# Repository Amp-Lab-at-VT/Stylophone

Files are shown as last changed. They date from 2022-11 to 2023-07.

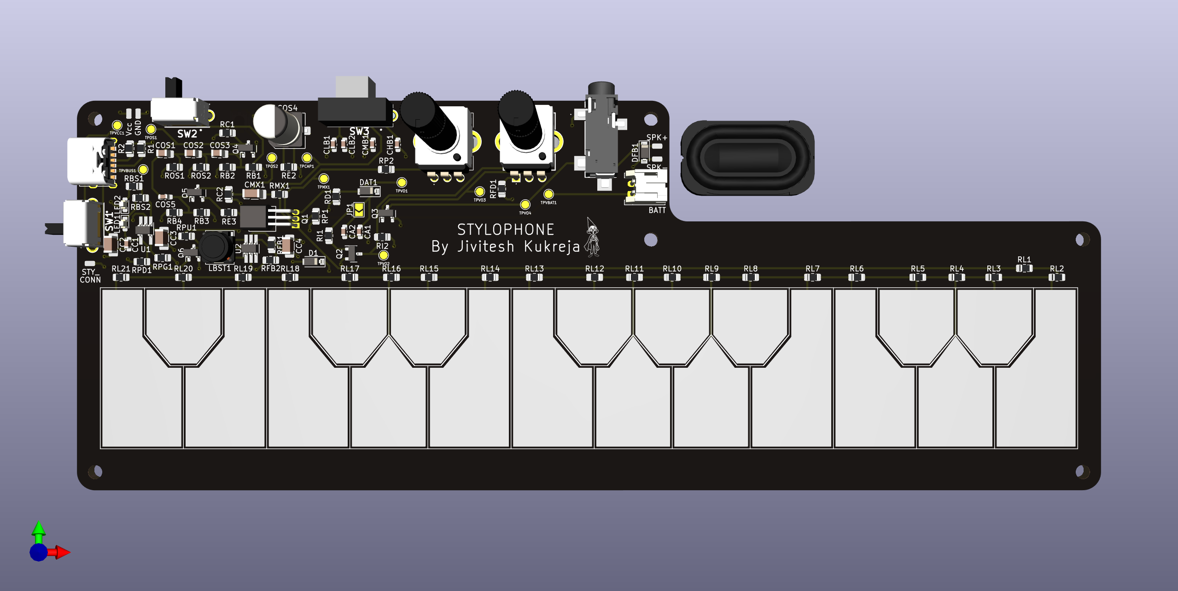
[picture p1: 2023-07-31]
Stylophone Circuit/PUT/Stylophone_with_battery_6.png

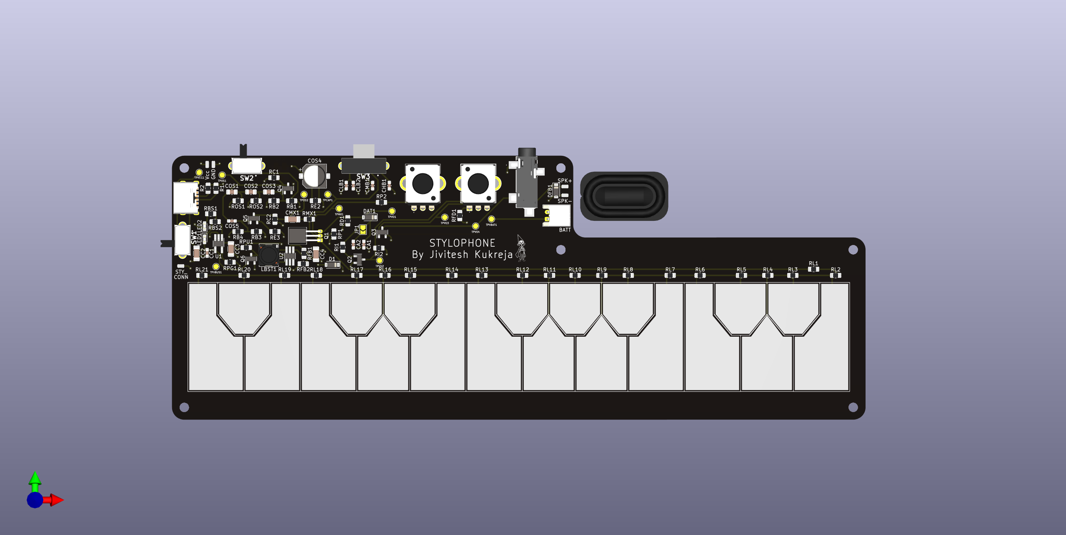
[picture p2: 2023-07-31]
Stylophone Circuit/PUT/Stylophone_with_battery_4.png

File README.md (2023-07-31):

## Members
Jivitesh Kukreja, Electrical Engineering (2024)\
jiviteshkuk26@vt.edu

## Repo Link
<a class="button is-link" href="https://github.com/Amp-Lab-at-VT/Stylophone">Stylophone</a>

## Photo
/web/img/Stylophone/hero.png

## Mentor
Richard Gibbons

## Current Status
In Progress

## Project Overview
# About Stylophone
Stylophone is a musical instrument that contains 20 keys each associated with a distinct musical note. Every time the stylus touches a key frequency associated with that key is heard on the speaker. 
Stylophone can shfit the octace associated with a key, up or down with a flick of a switch. There is also vibrato mode which is basically modulating the frequency of each key to make it sound "alienish".
# About This Project
This Project aims to reverse engineering a stylophone using a modern TLC555 timer IC and a old Programable Unijunction Transistor. 
The resevred engineered version aims to included modern features like power using type C, low power consumtion while idle and under load, support for low impedance speaker, and rechargable battery. 
This project also serves to see which sounds better the digital version based on the 555 timer or the analog version based on PUT as the orginal stylophone.

## Educational Value Added
This Project with help me learn:
1. How to design low frequency oscillators
2. How to a simple audio amplifier 
3. How to design PCB

## Tasks
1. Design a square wave generator using TLC555 that produces different frequencies with different resistor values.
2. Design an audio amplifier that drives the speaker.
3. Design a low-frequency sine wave generator for vibrato effect.
4. Power everything with a USB C connector. 

[//]: #Design Decisions

[//]: ## Design Misc

[//]: ## Steps for Documenting Your Design Process

## Fabrication Files
<a class="button is-link" href="https://github.com/Amp-Lab-at-VT/Stylophone/blob/main/Fabrication%20Files/PUT/gerber_files_with_battery.zip">Gerber Files</a>
<a class="button is-link" href="https://github.com/Amp-Lab-at-VT/Stylophone/blob/main/Fabrication%20Files/PUT/Stylophone_with_battery.csv">Bill Of Materials</a>

## Timeline
SEPTEMBER: Circuit Design\
OCTOBER: PCB Design and Protoboard Testing\
NOVEMBER: Assembly and Testing\

## Useful Links
https://www.waitingforfriday.com/?p=334 \
https://www.instructables.com/Retro-Stylophone-NE555-Based/

[//]: ## Log

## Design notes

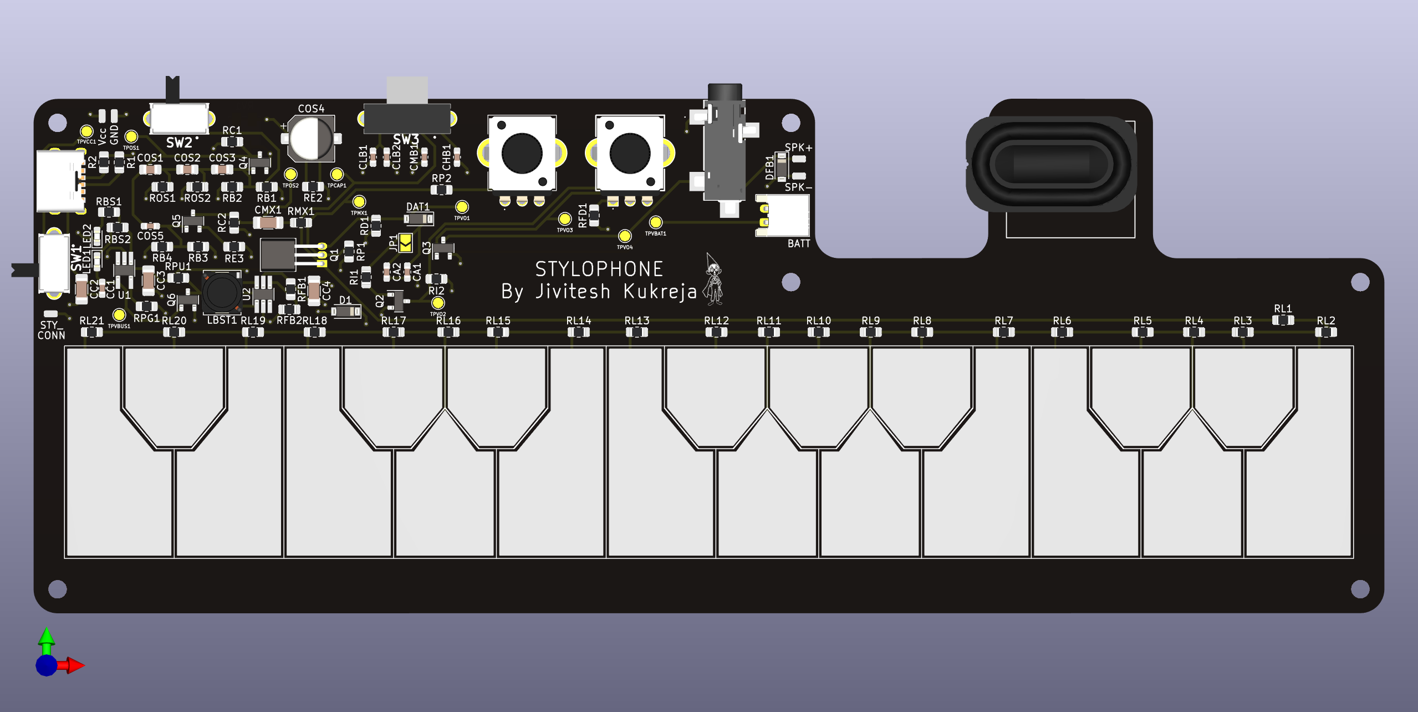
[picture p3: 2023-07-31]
Stylophone Circuit/PUT/Stylophone_with_battery_fun_design.png

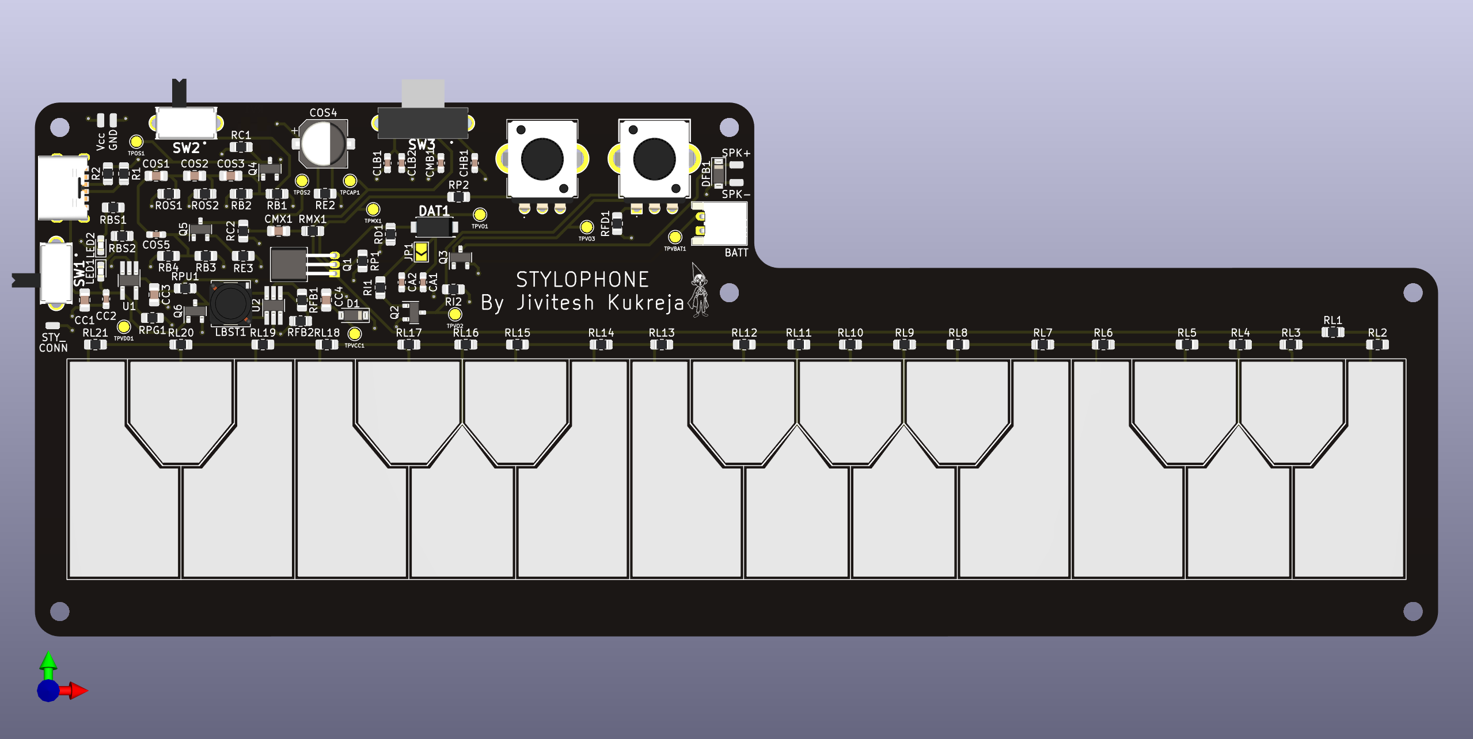
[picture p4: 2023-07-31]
Stylophone Circuit/PUT/Stylophone_with_battery.png

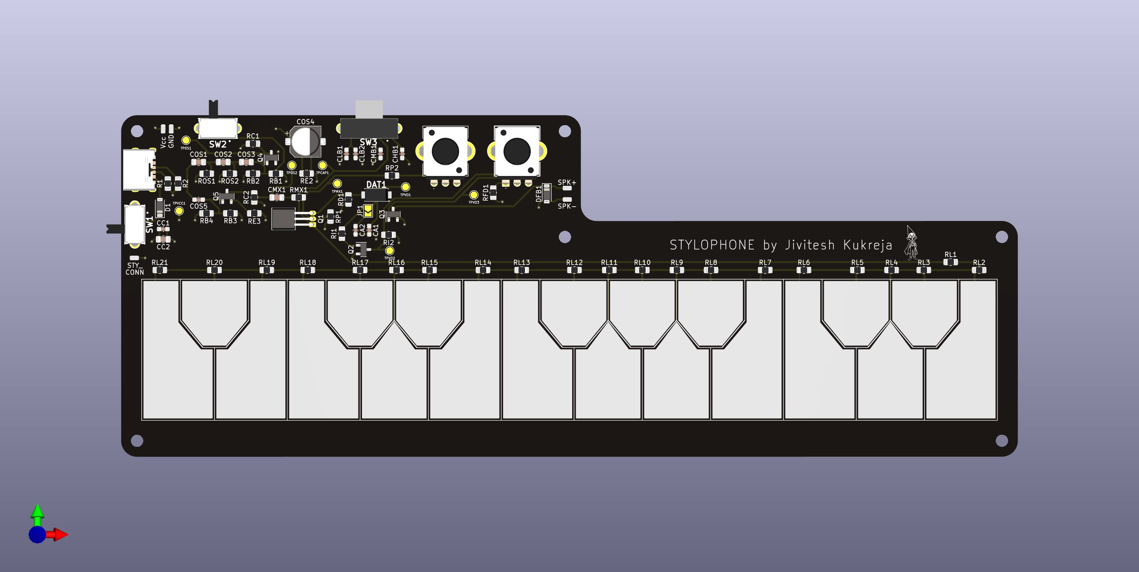
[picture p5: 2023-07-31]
Stylophone Circuit/PUT/Stylophone_without_battery.png

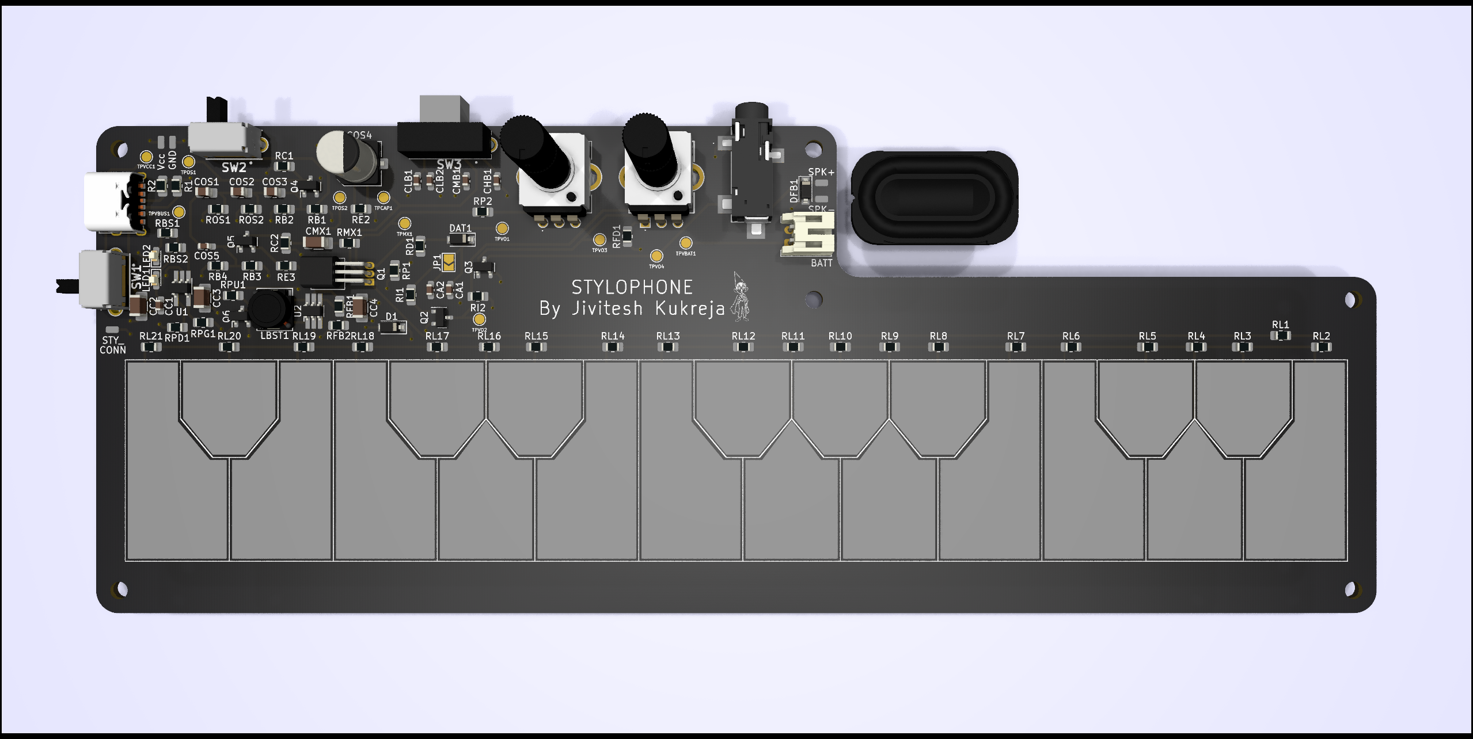
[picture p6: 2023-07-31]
Stylophone Circuit/PUT/Stylophone_with_battery_6_raytraced.png

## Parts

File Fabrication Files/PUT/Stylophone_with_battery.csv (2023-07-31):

Item | Q.R. | Reference(s) | Value | Footprint | Qty. To Order | Manufacturer | Manufacturer Part | Supplier Link | Unit Price For 1+($) | Unit Price For 10+($) | Ext. Price($) | Total Price($) | Comments
1 | 2 | CA1, CA2 | 10n | Capacitor_SMD:C_0603_1608Metric_Pad1.08x0.95mm_HandSolder | 10 | Samsung Electro-Mechanics | CL10B103KB8NNNC | https://www.mouser.com/ProductDetail/187-CL10B103KB8NNNC | 0.1 | 0.025 | 0.25 | 59.387
2 | 5 | CC1, CLB1, CLB2, CMB1, COS5 | 100n | Capacitor_SMD:C_0603_1608Metric_Pad1.08x0.95mm_HandSolder | 15 | Samsung Electro-Mechanics | CL10B104KB8NNNC | https://www.mouser.com/ProductDetail/187-CL10B104KB8NNNC | 0.1 | 0.028 | 0.42
3 | 1 | CHB1 | 47n | Capacitor_SMD:C_0603_1608Metric_Pad1.08x0.95mm_HandSolder | 10 | Samsung Electro-Mechanics | CL10B473KB8NNNC | https://www.mouser.com/ProductDetail/187-CL10B473KB8NNNC | 0.1 | 0.031 | 0.31
4 | 4 | CC2, CC3, CC4, CMX1 | 10u | Capacitor_SMD:C_1206_3216Metric_Pad1.33x1.80mm_HandSolder | 12 | Samsung Electro-Mechanics | CL31B106KBHNNNE | https://www.mouser.com/ProductDetail/187-CL31B106KBHNNNE | 0.33 | 0.232 | 2.784
5 | 3 | COS1, COS2, COS3 | 0.47u | Capacitor_SMD:C_0805_2012Metric_Pad1.18x1.45mm_HandSolder | 10 | Samsung Electro-Mechanics | CL21B474KBFNNNF | https://www.mouser.com/ProductDetail/187-CL21B474KBFNNNF | 0.1 | 0.06 | 0.6
6 | 1 | COS4 | 220u | Capacitor_SMD:CP_Elec_6.3x7.7 | 3 | Lelon | VZL221M1CTR-0607 | https://www.mouser.com/ProductDetail/140-VZL221M1CTR-0607 | 0.19 |  | 0.57 |  | UWT1V221MNL1GS, 865080453013, https://www.mouser.com/c/passive-components/capacitors/?capacitance=220%20uF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
7a | 3 | D1, DFB1, DAT1 | D_Schottky | Diode_SMD:D_SOD-123 | 10 | Nexperia | PMEG2005EGWX | https://www.mouser.com/ProductDetail/841-PMEG2005EGWX | 0.34 | 0.28 | 2.8
7b | 3 | D1, DFB2, DAT1 | D_Schottky | Diode_SMD:D_SOD-124 | 10 | Micro Commercial Components (MCC) | MBR0530-TP | https://www.mouser.com/ProductDetail/833-MBR0530-TP | 0.2 | 0.166 | 1.66
8 | 1 | J1 | USB_C_Receptacle_USB2.0 | LIB_GCT-USB4125-GF-A-190:GCTUSB4125GFA190 | 3 | Global Connector Technology (GCT) | USB4125-GF-A-0190 | https://www.mouser.com/ProductDetail/640-USB4125-GF-A-190 | 0.67 |  | 2.01
9 | 1 | J27 | Conn_01x02_Female | Connector_JST:JST_PH_S2B-PH-K_1x02_P2.00mm_Horizontal | 3 | JST Sales America Inc. | S2B-PH-K-S | https://www.digikey.com/en/products/detail/jst-sales-america-inc/S2B-PH-K-S-LF-SN/926626 | 0.17 |  | 0.51
10 | 1 | J28 | AudioJack2_Ground_SwitchT | SJ2-3593B-SMT-TR:SJ23593BSMTTR | 3 | CUI Devices | SJ2-3593B-SMT-TR | https://www.mouser.com/ProductDetail/490-SJ2-3593B-SMT-TR | 1.26 |  | 3.78
11 | 1 | LBST1 | 4.7u | 74408053004:74408053004_5030 | 3 | Wurth Elektronik | 74408053004 | https://www.mouser.com/ProductDetail/710-74408053004 | 1.04 |  | 3.12
12 | 1 | LED1 | Red | LED_SMD:LED_0603_1608Metric_Pad1.05x0.95mm_HandSolder | 3 | Wurth Elektronik | 150060SS75000 | https://www.mouser.com/ProductDetail/710-150060SS75000 | 0.15 |  | 0.45
13 | 1 | LED2 | Green | LED_SMD:LED_0603_1608Metric_Pad1.05x0.95mm_HandSolder | 3 | Wurth Elektronik | 150060VS75000 | https://www.mouser.com/ProductDetail/710-150060VS75000 | 0.15 |  | 0.45
14 | 1 | Q1 | 2N6027 | Package_TO_SOT_THT:TO-92_Inline_Horizontal2 | 3 | - | - | - | - |  | - |  | Acquired
15 | 3 | Q2, Q4, Q5 | MMBT3904L | Package_TO_SOT_SMD:SOT-23 | 9 | onsemi | MMBT3904LT3G | https://www.mouser.com/ProductDetail/863-MMBT3904LT3G | 0.13 |  | 1.17
16a | 1 | Q3 | pmos | Package_TO_SOT_SMD:SOT-23 | 3 | Microchip Technology | TP0610T-G | https://www.mouser.com/ProductDetail/689-TP0610T-G | 0.92 |  | 2.76
16b | 1 | Q3 | pmos | Package_TO_SOT_SMD:SOT-23 | 3 | Diodes Incorporated | DMP3099L-7 | https://www.mouser.com/ProductDetail/621-DMP3099L-7 | 0.34 |  | 1.02
17 | 1 | Q6 | 2N7002 | Package_TO_SOT_SMD:SOT-23 | 3 | onsemi | 2N7002LT1G | https://www.mouser.com/ProductDetail/863-2N7002LT1G | 0.29 |  | 0.87
18 | 2 | R1, R2 | 5.1k | Resistor_SMD:R_0805_2012Metric_Pad1.20x1.40mm_HandSolder | 10 | KOA Speer | RK73H2ATTD5101F | https://www.mouser.com/ProductDetail/660-RK73H2ATTD5101F | 0.1 | 0.021 | 0.21
19 | 1 | RB1 | 68k | Resistor_SMD:R_0805_2012Metric_Pad1.20x1.40mm_HandSolder | 10 | KOA Speer | RK73H2ATTD6802F | https://www.mouser.com/ProductDetail/660-RK73H2ATTD6802F | 0.1 | 0.021 | 0.21
20 | 1 | RB2 | 18k | Resistor_SMD:R_0805_2012Metric_Pad1.20x1.40mm_HandSolder | 10 | KOA Speer | RK73H2ATTD1802F | https://www.mouser.com/ProductDetail/660-RK73H2ATTD1802F | 0.1 | 0.021 | 0.21
21 | 1 | RB3 | 820k | Resistor_SMD:R_0805_2012Metric_Pad1.20x1.40mm_HandSolder | 10 | KOA Speer | RK73H2ATTD8203F | https://www.mouser.com/ProductDetail/660-RK73H2ATTD8203F | 0.1 | 0.021 | 0.21
22 | 1 | RB4 | 390k | Resistor_SMD:R_0805_2012Metric_Pad1.20x1.40mm_HandSolder | 10 | KOA Speer | RK73H2ATTD3903F | https://www.mouser.com/ProductDetail/660-RK73H2ATTD3903F | 0.1 | 0.021 | 0.21
23 | 2 | RBS1, RBS2 | 220 | Resistor_SMD:R_0805_2012Metric_Pad1.20x1.40mm_HandSolder | 10 | KOA Speer | RK73H2ATTD2200F | https://www.mouser.com/ProductDetail/660-RK73H2ATTD2200F | 0.1 | 0.021 | 0.21
24 | 2 | RC1, RL19 | 6.8k | Resistor_SMD:R_0805_2012Metric_Pad1.20x1.40mm_HandSolder | 10 | KOA Speer | RK73H2ATTD6801F | https://www.mouser.com/ProductDetail/660-RK73H2ATTD6801F | 0.1 | 0.021 | 0.21
25 | 5 | RC2, ROS1, ROS2, RPU1, RPD1 | 12k | Resistor_SMD:R_0805_2012Metric_Pad1.20x1.40mm_HandSolder | 15 | KOA Speer | RK73H2ATTD1202F | https://www.mouser.com/ProductDetail/660-RK73H2ATTD1202F | 0.1 | 0.021 | 0.252
26 | 1 | RD1 | 47 | Resistor_SMD:R_0805_2012Metric_Pad1.20x1.40mm_HandSolder | 10 | KOA Speer | RK73H2ATTD47R0F | https://www.mouser.com/ProductDetail/660-RK73H2ATTD47R0F | 0.1 | 0.021 | 0.21
27 | 7 | RE2, RI2, RL2, RL3, RMX1, RP1, RPG1 | 2.2k | Resistor_SMD:R_0805_2012Metric_Pad1.20x1.40mm_HandSolder | 21 | KOA Speer | RK73H2ATTD2201F | https://www.mouser.com/ProductDetail/660-RK73H2ATTD2201F | 0.1 | 0.021 | 0.441
28 | 5 | RE3, RL16, RL17, RL18, RL20 | 5.6k | Resistor_SMD:R_0805_2012Metric_Pad1.20x1.40mm_HandSolder | 15 | KOA Speer | RK73H2ATTD5601F | https://www.mouser.com/ProductDetail/660-RK73H2ATTD5601F | 0.1 | 0.021 | 0.315
29 | 1 | RFB1 | 900k | Resistor_SMD:R_0805_2012Metric_Pad1.20x1.40mm_HandSolder | 10 | KOA Speer | RK73H2ATTD9093F | https://www.mouser.com/ProductDetail/660-RK73H2ATTD9093F | 0.1 | 0.021 | 0.21
30 | 1 | RFB2 | 100k | Resistor_SMD:R_0805_2012Metric_Pad1.20x1.40mm_HandSolder | 10 | KOA Speer | RK73H2ATTD1003F | https://www.mouser.com/ProductDetail/660-RK73H2ATTD1003F | 0.1 | 0.021 | 0.21
31 | 3 | RFD1, RL4, RL5 | 2.7k | Resistor_SMD:R_0805_2012Metric_Pad1.20x1.40mm_HandSolder | 10 | KOA Speer | RK73H2ATTD2701F | https://www.mouser.com/ProductDetail/660-RK73H2ATTD2701F | 0.1 | 0.021 | 0.21
32 | 2 | RI1, RL1 | 39k | Resistor_SMD:R_0805_2012Metric_Pad1.20x1.40mm_HandSolder | 10 | KOA Speer | RK73H2ATTD3902F | https://www.mouser.com/ProductDetail/660-RK73H2ATTD3902F | 0.1 | 0.021 | 0.21
33 | 4 | RL6, RL7, RL8, RL9 | 3.3k | Resistor_SMD:R_0805_2012Metric_Pad1.20x1.40mm_HandSolder | 12 | KOA Speer | RK73H2ATTD3301F | https://www.mouser.com/ProductDetail/660-RK73H2ATTD3301F | 0.1 | 0.021 | 0.252
34 | 3 | RL10, RL11, RL12 | 3.9k | Resistor_SMD:R_0805_2012Metric_Pad1.20x1.40mm_HandSolder | 10 | KOA Speer | RK73H2ATTD3901F | https://www.mouser.com/ProductDetail/660-RK73H2ATTD3901F | 0.1 | 0.021 | 0.21
35 | 3 | RL13, RL14, RL15 | 4.7k | Resistor_SMD:R_0805_2012Metric_Pad1.20x1.40mm_HandSolder | 10 | KOA Speer | RK73H2ATTD4701F | https://www.mouser.com/ProductDetail/660-RK73H2ATTD4701F | 0.1 | 0.021 | 0.21
36 | 1 | RL21 | 8.2k | Resistor_SMD:R_0805_2012Metric_Pad1.20x1.40mm_HandSolder | 10 | KOA Speer | RK73H2ATTD8201F | https://www.mouser.com/ProductDetail/660-RK73H2ATTD8201F | 0.1 | 0.021 | 0.21
37 | 1 | RP2 | 1.8k | Resistor_SMD:R_0805_2012Metric_Pad1.20x1.40mm_HandSolder | 10 | KOA Speer | RK73H2ATTD1801F | https://www.mouser.com/ProductDetail/660-RK73H2ATTD1801F | 0.1 | 0.021 | 0.21
38 | 1 | RV1 | R_Potentiometer_Trim(100) | TC33X-2-101E:TC33X2503E | 3 | Bourns | TC33X-2-101E | https://www.mouser.com/ProductDetail/652-TC33X-2-101E | 0.28 |  | 0.84
39 | 2 | SW1, SW2 | SW_SPDT | OS102011MA1QN1:OS102011MA1QN1 | 6 | C&K Switches | OS102011MA1QN1 | https://www.mouser.com/ProductDetail/611-OS102011MA1QN1 | 0.5 |  | 3
40 | 1 | SW3 | SW_SP3T | OS103011MA7QP1:OS103011MA7QP1 | 3 | C&K Switches | OS103011MA7QP1 | https://www.mouser.com/ProductDetail/611-OS103011MA7QP1 | 0.58 |  | 1.74
41 | 1 | U1 | MCP73831T-4ADI_OT | Package_TO_SOT_SMD:TSOT-23-5_HandSoldering | 3 | Microchip Technology | MCP73831T-4ADI/OT | https://www.mouser.com/ProductDetail/579-MCP73831T4ADIOT | 0.76 |  | 2.28
42 | 1 | U2 | DIO6305B | Package_TO_SOT_SMD:TSOT-23-6_HandSoldering | 3 | DIOO Microcircuits | DIO6305BCST6 | https://www.mouser.com/ProductDetail/453-DIO6305BCST6 | 0.6 |  | 1.8
43 | 1 | VR1 | PTV09A-4025F-B102 | PTV09A-4025F-B102:PTV09A4025FB102 | 3 | Bourns | PTV09A-4025F-B102 | https://www.mouser.com/ProductDetail/652-PTV09A-4025FB102 | 1.01 |  | 3.03
44 | 1 | VR2 | PTV09A-4025F-A103 | PTV09A-4025F-A103:PTV09A4025FA103 | 3 | Bourns | PTV09A-4025F-A103 | https://www.mouser.com/ProductDetail/652-PTV09A4025FA103 | 1.01 |  | 3.03
45 | 1 | - | Lithium Ion Polymer Battery - 3.7v 1200mAh | - | 1 | Adafruit | 258 | https://www.adafruit.com/product/258 | 9.95 |  | 9.95
46 | 1 | - | Speaker, 25 x 14mm rectangle, 5mm deep | - | 1 | CUI Devices | CMS-25145-28SP-67 | https://www.mouser.com/ProductDetail/490-CMS-25145-28SP67 | 3.5 |  | 3.5

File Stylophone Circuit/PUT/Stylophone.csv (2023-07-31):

Source: | C:\Users\jivit\Documents\Stylophone\Amp Lab Project Repo\Stylophone\Stylophone Circuit\PUT\Stylophone.kicad_sch
Date: | 21-07-2023 8.14.33 PM
Tool: | Eeschema (6.0.7)
Generator: | C:\Program Files\KiCad\6.0\bin\scripting\plugins/bom_csv_grouped_by_value.py
Component Count: | 128
Individual Components:
Item | Qty | Reference(s) | Value | LibPart | Footprint | Datasheet | Datasheet_1 | Footprint_1 | Height | Manufacturer_Name | Manufacturer_Part_Number | Mouser Part Number | Mouser Price/Stock
 |  | CA1 | 10n | pspice:C | Capacitor_SMD:C_0603_1608Metric_Pad1.08x0.95mm_HandSolder | ~
 |  | CA2 | 10n | pspice:C | Capacitor_SMD:C_0603_1608Metric_Pad1.08x0.95mm_HandSolder | ~
 |  | CC1 | 100n | pspice:C | Capacitor_SMD:C_0603_1608Metric_Pad1.08x0.95mm_HandSolder | ~
 |  | CC2 | 10u | pspice:C | Capacitor_SMD:C_1206_3216Metric_Pad1.33x1.80mm_HandSolder | ~
 |  | CC3 | 10u | pspice:C | Capacitor_SMD:C_1206_3216Metric_Pad1.33x1.80mm_HandSolder | ~
 |  | CC4 | 10u | pspice:C | Capacitor_SMD:C_1206_3216Metric_Pad1.33x1.80mm_HandSolder | ~
 |  | CHB1 | 47n | pspice:C | Capacitor_SMD:C_0603_1608Metric_Pad1.08x0.95mm_HandSolder | ~
 |  | CLB1 | 100n | pspice:C | Capacitor_SMD:C_0603_1608Metric_Pad1.08x0.95mm_HandSolder | ~
 |  | CLB2 | 100n | pspice:C | Capacitor_SMD:C_0603_1608Metric_Pad1.08x0.95mm_HandSolder | ~
 |  | CMB1 | 100n | pspice:C | Capacitor_SMD:C_0603_1608Metric_Pad1.08x0.95mm_HandSolder | ~
 |  | CMX1 | 10u | pspice:C | Capacitor_SMD:C_1206_3216Metric_Pad1.33x1.80mm_HandSolder | ~
 |  | COS1 | 0.47u | pspice:C | Capacitor_SMD:C_0805_2012Metric_Pad1.18x1.45mm_HandSolder | ~
 |  | COS2 | 0.47u | pspice:C | Capacitor_SMD:C_0805_2012Metric_Pad1.18x1.45mm_HandSolder | ~
 |  | COS3 | 0.47u | pspice:C | Capacitor_SMD:C_0805_2012Metric_Pad1.18x1.45mm_HandSolder | ~
 |  | COS4 | 220u | pspice:C | Capacitor_SMD:CP_Elec_6.3x7.7 | ~
 |  | COS5 | 100n | pspice:C | Capacitor_SMD:C_0603_1608Metric_Pad1.08x0.95mm_HandSolder | ~
 |  | D1 | D_Schottky | Device:D_Schottky | Diode_SMD:D_SOD-123 | ~
 |  | DAT1 | D_Schottky | S1A:S1A | Diode_SMD:D_SOD-123 | https://www.mouser.com/datasheet/2/308/1/S1M_D-2320166.pdf | http://www.onsemi.com/pub/Collateral/S1M-D.pdf | DIOM5227X270N | 2.7 | onsemi | S1A | 512-S1A | https://www.mouser.co.uk/ProductDetail/onsemi-Fairchild/S1A?qs=RJwZ8kJo1mjAagviH5vK9g%3D%3D
 |  | DFB1 | D_Schottky | Device:D_Schottky | Diode_SMD:D_SOD-123 | ~
 |  | H1 | MountingHole | Mechanical:MountingHole | MountingHole:MountingHole_2.7mm_M2.5 | ~
 |  | H2 | MountingHole | Mechanical:MountingHole | MountingHole:MountingHole_2.7mm_M2.5 | ~
 |  | H3 | MountingHole | Mechanical:MountingHole | MountingHole:MountingHole_2.7mm_M2.5 | ~
 |  | H4 | MountingHole | Mechanical:MountingHole | MountingHole:MountingHole_2.7mm_M2.5 | ~
 |  | H5 | MountingHole | Mechanical:MountingHole | MountingHole:MountingHole_2.7mm_M2.5 | ~
 |  | H6 | MountingHole | Mechanical:MountingHole | MountingHole:MountingHole_2.7mm_M2.5 | ~
 |  | J1 | USB_C_Receptacle_USB2.0 | Connector:USB_C_Receptacle_USB2.0 | LIB_GCT-USB4125-GF-A-190:GCTUSB4125GFA190 | https://www.usb.org/sites/default/files/documents/usb_type-c.zip
 |  | J2 | Conn_01x01_Female | Connector:Conn_01x01_Female | Connector_Wire:SolderWirePad_1x01_SMD_1x2mm | ~
 |  | J3 | Conn_01x01_Female | Connector:Conn_01x01_Female | Connector_Wire:SolderWirePad_1x01_SMD_1x2mm | ~
 |  | J4 | Conn_01x01_Female | Connector:Conn_01x01_Female | Connector_Wire:SolderWirePad_1x01_SMD_1x2mm | ~
 |  | J5 | Conn_01x01_Female | Connector:Conn_01x01_Female | Stylophone_Lib:Note-Left | ~
 |  | J6 | Conn_01x01_Female | Connector:Conn_01x01_Female | Stylophone_Lib:Note-Sharp | ~
 |  | J7 | Conn_01x01_Female | Connector:Conn_01x01_Female | Stylophone_Lib:Note-Right | ~
 |  | J8 | Conn_01x01_Female | Connector:Conn_01x01_Female | Stylophone_Lib:Note-Left | ~
 |  | J9 | Conn_01x01_Female | Connector:Conn_01x01_Female | Stylophone_Lib:Note-Sharp | ~
 |  | J10 | Conn_01x01_Female | Connector:Conn_01x01_Female | Stylophone_Lib:Note-Center | ~
 |  | J11 | Conn_01x01_Female | Connector:Conn_01x01_Female | Stylophone_Lib:Note-Sharp | ~
 |  | J12 | Conn_01x01_Female | Connector:Conn_01x01_Female | Stylophone_Lib:Note-Right | ~
 |  | J13 | Conn_01x01_Female | Connector:Conn_01x01_Female | Stylophone_Lib:Note-Left | ~
 |  | J14 | Conn_01x01_Female | Connector:Conn_01x01_Female | Stylophone_Lib:Note-Sharp | ~
 |  | J15 | Conn_01x01_Female | Connector:Conn_01x01_Female | Stylophone_Lib:Note-Right | ~
 |  | J16 | Conn_01x01_Female | Connector:Conn_01x01_Female | Stylophone_Lib:Note-Sharp | ~
 |  | J17 | Conn_01x01_Female | Connector:Conn_01x01_Female | Stylophone_Lib:Note-Center | ~
 |  | J18 | Conn_01x01_Female | Connector:Conn_01x01_Female | Stylophone_Lib:Note-Sharp | ~
 |  | J19 | Conn_01x01_Female | Connector:Conn_01x01_Female | Stylophone_Lib:Note-Left | ~
 |  | J20 | Conn_01x01_Female | Connector:Conn_01x01_Female | Stylophone_Lib:Note-Right | ~
 |  | J21 | Conn_01x01_Female | Connector:Conn_01x01_Female | Stylophone_Lib:Note-Sharp | ~
 |  | J22 | Conn_01x01_Female | Connector:Conn_01x01_Female | Stylophone_Lib:Note-Center | ~
 |  | J23 | Conn_01x01_Female | Connector:Conn_01x01_Female | Stylophone_Lib:Note-Sharp | ~
 |  | J24 | Conn_01x01_Female | Connector:Conn_01x01_Female | Stylophone_Lib:Note-Center | ~
 |  | J25 | Conn_01x01_Female | Connector:Conn_01x01_Female | Connector_Wire:SolderWirePad_1x01_SMD_1x2mm | ~
 |  | J26 | Conn_01x01_Female | Connector:Conn_01x01_Female | Connector_Wire:SolderWirePad_1x01_SMD_1x2mm | ~
 |  | J27 | Conn_01x02_Female | Connector:Conn_01x02_Female | Connector_JST:JST_PH_S2B-PH-K_1x02_P2.00mm_Horizontal | ~
 |  | J28 | AudioJack2_Ground_SwitchT | Connector:AudioJack2_Ground_SwitchT | SJ2-3593B-SMT-TR:SJ23593BSMTTR | ~
 |  | JP1 | SolderJumper_2_Open | Jumper:SolderJumper_2_Open | Jumper:SolderJumper-2_P1.3mm_Open_TrianglePad1.0x1.5mm | ~
 |  | LBST1 | 4.7u | pspice:INDUCTOR | 74408053004:74408053004_5030 | ~
 |  | LED1 | Red | Device:LED | LED_SMD:LED_0603_1608Metric_Pad1.05x0.95mm_HandSolder | ~
 |  | LED2 | Green | Device:LED | LED_SMD:LED_0603_1608Metric_Pad1.05x0.95mm_HandSolder | ~
 |  | Q1 | 2N6027 | Transistor_PUT:2N6027 | Package_TO_SOT_THT:TO-92_Inline_Horizontal2 | https://www.mouser.com/datasheet/2/68/get_document-1518606.pdf
 |  | Q2 | MMBT3904L | Transistor_BJT:MMBT3904 | Package_TO_SOT_SMD:SOT-23 | https://www.onsemi.com/pub/Collateral/2N3903-D.PDF
 |  | Q3 | TP0610T | Transistor_FET:TP0610T | Package_TO_SOT_SMD:SOT-23 | http://www.vishay.com/docs/70209/70209.pdf
 |  | Q4 | MMBT3904L | Transistor_BJT:MMBT3904 | Package_TO_SOT_SMD:SOT-23 | https://www.onsemi.com/pub/Collateral/2N3903-D.PDF
 |  | Q5 | MMBT3904L | Transistor_BJT:MMBT3904 | Package_TO_SOT_SMD:SOT-23 | https://www.onsemi.com/pub/Collateral/2N3903-D.PDF
 |  | Q6 | 2N7002 | Transistor_FET:2N7002 | Package_TO_SOT_SMD:SOT-23 | https://www.onsemi.com/pub/Collateral/NDS7002A-D.PDF
 |  | R1 | 5.1k | Device:R | Resistor_SMD:R_0805_2012Metric_Pad1.20x1.40mm_HandSolder | ~
 |  | R2 | 5.1k | Device:R | Resistor_SMD:R_0805_2012Metric_Pad1.20x1.40mm_HandSolder | ~
 |  | RB1 | 68k | Device:R | Resistor_SMD:R_0805_2012Metric_Pad1.20x1.40mm_HandSolder | ~
 |  | RB2 | 18k | Device:R | Resistor_SMD:R_0805_2012Metric_Pad1.20x1.40mm_HandSolder | ~
 |  | RB3 | 820k | Device:R | Resistor_SMD:R_0805_2012Metric_Pad1.20x1.40mm_HandSolder | ~
 |  | RB4 | 390k | Device:R | Resistor_SMD:R_0805_2012Metric_Pad1.20x1.40mm_HandSolder | ~
 |  | RBS1 | 220 | Device:R | Resistor_SMD:R_0805_2012Metric_Pad1.20x1.40mm_HandSolder | ~
 |  | RBS2 | 220 | Device:R | Resistor_SMD:R_0805_2012Metric_Pad1.20x1.40mm_HandSolder | ~
 |  | RC1 | 6.8k | Device:R | Resistor_SMD:R_0805_2012Metric_Pad1.20x1.40mm_HandSolder | ~
 |  | RC2 | 12k | Device:R | Resistor_SMD:R_0805_2012Metric_Pad1.20x1.40mm_HandSolder | ~
 |  | RD1 | 47 | Device:R | Resistor_SMD:R_0805_2012Metric_Pad1.20x1.40mm_HandSolder | ~
 |  | RE2 | 2.2k | Device:R | Resistor_SMD:R_0805_2012Metric_Pad1.20x1.40mm_HandSolder | ~
 |  | RE3 | 5.6k | Device:R | Resistor_SMD:R_0805_2012Metric_Pad1.20x1.40mm_HandSolder | ~
 |  | RFB1 | 900k | Device:R | Resistor_SMD:R_0805_2012Metric_Pad1.20x1.40mm_HandSolder | ~
 |  | RFB2 | 100k | Device:R | Resistor_SMD:R_0805_2012Metric_Pad1.20x1.40mm_HandSolder | ~
 |  | RFD1 | 2.7k | Device:R | Resistor_SMD:R_0805_2012Metric_Pad1.20x1.40mm_HandSolder | ~
 |  | RI1 | 39k | Device:R | Resistor_SMD:R_0805_2012Metric_Pad1.20x1.40mm_HandSolder | ~
 |  | RI2 | 2.2k | Device:R | Resistor_SMD:R_0805_2012Metric_Pad1.20x1.40mm_HandSolder | ~
 |  | RL1 | 39k | Device:R | Resistor_SMD:R_0805_2012Metric_Pad1.20x1.40mm_HandSolder | ~
 |  | RL2 | 2.2k | Device:R | Resistor_SMD:R_0805_2012Metric_Pad1.20x1.40mm_HandSolder | ~
 |  | RL3 | 2.2k | Device:R | Resistor_SMD:R_0805_2012Metric_Pad1.20x1.40mm_HandSolder | ~
 |  | RL4 | 2.7k | Device:R | Resistor_SMD:R_0805_2012Metric_Pad1.20x1.40mm_HandSolder | ~
 |  | RL5 | 2.7k | Device:R | Resistor_SMD:R_0805_2012Metric_Pad1.20x1.40mm_HandSolder | ~
 |  | RL6 | 3.3k | Device:R | Resistor_SMD:R_0805_2012Metric_Pad1.20x1.40mm_HandSolder | ~
 |  | RL7 | 3.3k | Device:R | Resistor_SMD:R_0805_2012Metric_Pad1.20x1.40mm_HandSolder | ~
 |  | RL8 | 3.3k | Device:R | Resistor_SMD:R_0805_2012Metric_Pad1.20x1.40mm_HandSolder | ~
 |  | RL9 | 3.3k | Device:R | Resistor_SMD:R_0805_2012Metric_Pad1.20x1.40mm_HandSolder | ~
 |  | RL10 | 3.9k | Device:R | Resistor_SMD:R_0805_2012Metric_Pad1.20x1.40mm_HandSolder | ~
 |  | RL11 | 3.9k | Device:R | Resistor_SMD:R_0805_2012Metric_Pad1.20x1.40mm_HandSolder | ~
 |  | RL12 | 3.9k | Device:R | Resistor_SMD:R_0805_2012Metric_Pad1.20x1.40mm_HandSolder | ~
 |  | RL13 | 4.7k | Device:R | Resistor_SMD:R_0805_2012Metric_Pad1.20x1.40mm_HandSolder | ~
 |  | RL14 | 4.7k | Device:R | Resistor_SMD:R_0805_2012Metric_Pad1.20x1.40mm_HandSolder | ~
 |  | RL15 | 4.7k | Device:R | Resistor_SMD:R_0805_2012Metric_Pad1.20x1.40mm_HandSolder | ~
 |  | RL16 | 5.6k | Device:R | Resistor_SMD:R_0805_2012Metric_Pad1.20x1.40mm_HandSolder | ~
 |  | RL17 | 5.6k | Device:R | Resistor_SMD:R_0805_2012Metric_Pad1.20x1.40mm_HandSolder | ~
 |  | RL18 | 5.6k | Device:R | Resistor_SMD:R_0805_2012Metric_Pad1.20x1.40mm_HandSolder | ~
 |  | RL19 | 6.8k | Device:R | Resistor_SMD:R_0805_2012Metric_Pad1.20x1.40mm_HandSolder | ~
 |  | RL20 | 5.6k | Device:R | Resistor_SMD:R_0805_2012Metric_Pad1.20x1.40mm_HandSolder | ~
 |  | RL21 | 8.2k | Device:R | Resistor_SMD:R_0805_2012Metric_Pad1.20x1.40mm_HandSolder | ~
 |  | RMX1 | 2.2k | Device:R | Resistor_SMD:R_0805_2012Metric_Pad1.20x1.40mm_HandSolder | ~
 |  | ROS1 | 12k | Device:R | Resistor_SMD:R_0805_2012Metric_Pad1.20x1.40mm_HandSolder | ~
 |  | ROS2 | 12k | Device:R | Resistor_SMD:R_0805_2012Metric_Pad1.20x1.40mm_HandSolder | ~
 |  | RP1 | 2.2k | Device:R | Resistor_SMD:R_0805_2012Metric_Pad1.20x1.40mm_HandSolder | ~
 |  | RP2 | 1.8k | Device:R | Resistor_SMD:R_0805_2012Metric_Pad1.20x1.40mm_HandSolder | ~
 |  | RPG1 | 2.2k | Device:R | Resistor_SMD:R_0805_2012Metric_Pad1.20x1.40mm_HandSolder | ~
 |  | RPU1 | 12k | Device:R | Resistor_SMD:R_0805_2012Metric_Pad1.20x1.40mm_HandSolder | ~
 |  | RV1 | R_Potentiometer_Trim(100) | Device:R_Potentiometer_Trim | Potentiometer_SMD:Potentiometer_Bourns_3314J_Vertical | ~
 |  | SW1 | SW_SPDT | Switch:SW_SPDT | OS102011MA1QN1:OS102011MA1QN1 | ~
 |  | SW2 | SW_SPDT | Switch:SW_SPDT | OS102011MA1QN1:OS102011MA1QN1 | ~
 |  | SW3 | SW_SP3T | Switch:SW_SP3T | OS103011MA7QP1:OS103011MA7QP1 | ~
 |  | TPCAP1 | TestPoint | Connector:TestPoint | TestPoint:TestPoint_Pad_D1.5mm | ~
 |  | TPMX1 | TestPoint | Connector:TestPoint | TestPoint:TestPoint_Pad_D1.5mm | ~
 |  | TPOS1 | TestPoint | Connector:TestPoint | TestPoint:TestPoint_Pad_D1.5mm | ~
 |  | TPOS2 | TestPoint | Connector:TestPoint | TestPoint:TestPoint_Pad_D1.5mm | ~
 |  | TPVBAT1 | TestPoint | Connector:TestPoint | TestPoint:TestPoint_Pad_D1.5mm | ~
 |  | TPVBUS1 | TestPoint | Connector:TestPoint | TestPoint:TestPoint_Pad_D1.5mm | ~
 |  | TPVCC1 | TestPoint | Connector:TestPoint | TestPoint:TestPoint_Pad_D1.5mm | ~
 |  | TPVO1 | TestPoint | Connector:TestPoint | TestPoint:TestPoint_Pad_D1.5mm | ~
 |  | TPVO2 | TestPoint | Connector:TestPoint | TestPoint:TestPoint_Pad_D1.5mm | ~
 |  | TPVO3 | TestPoint | Connector:TestPoint | TestPoint:TestPoint_Pad_D1.5mm | ~
 |  | TPVO4 | TestPoint | Connector:TestPoint | TestPoint:TestPoint_Pad_D1.5mm | ~
 |  | U1 | MCP73831T-4ADI_OT | MCP73831T-4ADI_OT:MCP73831T-4ADI_OT | Package_TO_SOT_SMD:TSOT-23-5_HandSoldering |  | https://componentsearchengine.com/Datasheets/1/MCP73831T-4ADI_OT.pdf | SOT95P270X145-5N | 1.45 | Microchip | MCP73831T-4ADI/OT | 579-MCP73831T4ADIOT | https://www.mouser.co.uk/ProductDetail/Microchip-Technology/MCP73831T-4ADI-OT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
 |  | U2 | DIO6305B | LIB_DIO6305B_sym:DIO6305B | Package_TO_SOT_SMD:TSOT-23-6_HandSoldering
 |  | VR1 | PTV09A-4025F-B102 | PTV09A-4025F-B102:PTV09A-4025F-B102 | PTV09A-4025F-B102:PTV09A4025FB102 | https://www.mouser.com/datasheet/2/54/ptv09-777818.pdf | https://datasheet.datasheetarchive.com/originals/dk/DKDS-12/224967.pdf | PTV09A4025FB102 | 25.5 | Bourns | PTV09A-4025F-B102 | 652-PTV09A-4025FB102 | https://www.mouser.co.uk/ProductDetail/Bourns/PTV09A-4025F-B102?qs=Qzws7J6gxqxMpvIOw8B%2F7Q%3D%3D
 |  | VR2 | PTV09A-4025F-A103 | PTV09A-4025F-A103:PTV09A-4025F-A103 | PTV09A-4025F-A103:PTV09A4025FA103 | https://www.mouser.com/datasheet/2/54/ptv09-777818.pdf | https://www.bourns.com/docs/Product-Datasheets/PTV09.pdf | PTV09A4025FA103 | 25.5 | Bourns | PTV09A-4025F-A103 | 652-PTV09A4025FA103 | https://www.mouser.co.uk/ProductDetail/Bourns/PTV09A-4025F-A103?qs=%2FxQVPCMPNzjerVjIRRaAEA%3D%3D
Collated Components:
Item | Qty | Reference(s) | Value | LibPart | Footprint | Datasheet | Datasheet_1 | Footprint_1 | Height | Manufacturer_Name | Manufacturer_Part_Number | Mouser Part Number | Mouser Price/Stock
1 | 2 | CA1, CA2 | 10n | pspice:C | Capacitor_SMD:C_0603_1608Metric_Pad1.08x0.95mm_HandSolder | ~
2 | 5 | CC1, CLB1, CLB2, CMB1, COS5 | 100n | pspice:C | Capacitor_SMD:C_0603_1608Metric_Pad1.08x0.95mm_HandSolder | ~
3 | 4 | CC2, CC3, CC4, CMX1 | 10u | pspice:C | Capacitor_SMD:C_1206_3216Metric_Pad1.33x1.80mm_HandSolder | ~
4 | 1 | CHB1 | 47n | pspice:C | Capacitor_SMD:C_0603_1608Metric_Pad1.08x0.95mm_HandSolder | ~
5 | 3 | COS1, COS2, COS3 | 0.47u | pspice:C | Capacitor_SMD:C_0805_2012Metric_Pad1.18x1.45mm_HandSolder | ~
6 | 1 | COS4 | 220u | pspice:C | Capacitor_SMD:CP_Elec_6.3x7.7 | ~
7 | 2 | D1, DFB1 | D_Schottky | Device:D_Schottky | Diode_SMD:D_SOD-123 | ~
8 | 1 | DAT1 | D_Schottky | S1A:S1A | Diode_SMD:D_SOD-123 | https://www.mouser.com/datasheet/2/308/1/S1M_D-2320166.pdf | http://www.onsemi.com/pub/Collateral/S1M-D.pdf | DIOM5227X270N | 2.7 | onsemi | S1A | 512-S1A | https://www.mouser.co.uk/ProductDetail/onsemi-Fairchild/S1A?qs=RJwZ8kJo1mjAagviH5vK9g%3D%3D
9 | 6 | H1, H2, H3, H4, H5, H6 | MountingHole | Mechanical:MountingHole | MountingHole:MountingHole_2.7mm_M2.5 | ~
10 | 1 | J1 | USB_C_Receptacle_USB2.0 | Connector:USB_C_Receptacle_USB2.0 | LIB_GCT-USB4125-GF-A-190:GCTUSB4125GFA190 | https://www.usb.org/sites/default/files/documents/usb_type-c.zip
11 | 5 | J2, J3, J4, J25, J26 | Conn_01x01_Female | Connector:Conn_01x01_Female | Connector_Wire:SolderWirePad_1x01_SMD_1x2mm | ~
12 | 4 | J5, J8, J13, J19 | Conn_01x01_Female | Connector:Conn_01x01_Female | Stylophone_Lib:Note-Left | ~
13 | 8 | J6, J9, J11, J14, J16, J18, J21, J23 | Conn_01x01_Female | Connector:Conn_01x01_Female | Stylophone_Lib:Note-Sharp | ~
14 | 4 | J7, J12, J15, J20 | Conn_01x01_Female | Connector:Conn_01x01_Female | Stylophone_Lib:Note-Right | ~
15 | 4 | J10, J17, J22, J24 | Conn_01x01_Female | Connector:Conn_01x01_Female | Stylophone_Lib:Note-Center | ~
16 | 1 | J27 | Conn_01x02_Female | Connector:Conn_01x02_Female | Connector_JST:JST_PH_S2B-PH-K_1x02_P2.00mm_Horizontal | ~
17 | 1 | J28 | AudioJack2_Ground_SwitchT | Connector:AudioJack2_Ground_SwitchT | SJ2-3593B-SMT-TR:SJ23593BSMTTR | ~
18 | 1 | JP1 | SolderJumper_2_Open | Jumper:SolderJumper_2_Open | Jumper:SolderJumper-2_P1.3mm_Open_TrianglePad1.0x1.5mm | ~
19 | 1 | LBST1 | 4.7u | pspice:INDUCTOR | 74408053004:74408053004_5030 | ~
20 | 1 | LED1 | Red | Device:LED | LED_SMD:LED_0603_1608Metric_Pad1.05x0.95mm_HandSolder | ~
21 | 1 | LED2 | Green | Device:LED | LED_SMD:LED_0603_1608Metric_Pad1.05x0.95mm_HandSolder | ~
22 | 1 | Q1 | 2N6027 | Transistor_PUT:2N6027 | Package_TO_SOT_THT:TO-92_Inline_Horizontal2 | https://www.mouser.com/datasheet/2/68/get_document-1518606.pdf
23 | 3 | Q2, Q4, Q5 | MMBT3904L | Transistor_BJT:MMBT3904 | Package_TO_SOT_SMD:SOT-23 | https://www.onsemi.com/pub/Collateral/2N3903-D.PDF
24 | 1 | Q3 | TP0610T | Transistor_FET:TP0610T | Package_TO_SOT_SMD:SOT-23 | http://www.vishay.com/docs/70209/70209.pdf
25 | 1 | Q6 | 2N7002 | Transistor_FET:2N7002 | Package_TO_SOT_SMD:SOT-23 | https://www.onsemi.com/pub/Collateral/NDS7002A-D.PDF
26 | 2 | R1, R2 | 5.1k | Device:R | Resistor_SMD:R_0805_2012Metric_Pad1.20x1.40mm_HandSolder | ~
27 | 1 | RB1 | 68k | Device:R | Resistor_SMD:R_0805_2012Metric_Pad1.20x1.40mm_HandSolder | ~
28 | 1 | RB2 | 18k | Device:R | Resistor_SMD:R_0805_2012Metric_Pad1.20x1.40mm_HandSolder | ~
29 | 1 | RB3 | 820k | Device:R | Resistor_SMD:R_0805_2012Metric_Pad1.20x1.40mm_HandSolder | ~
30 | 1 | RB4 | 390k | Device:R | Resistor_SMD:R_0805_2012Metric_Pad1.20x1.40mm_HandSolder | ~
31 | 2 | RBS1, RBS2 | 220 | Device:R | Resistor_SMD:R_0805_2012Metric_Pad1.20x1.40mm_HandSolder | ~
32 | 2 | RC1, RL19 | 6.8k | Device:R | Resistor_SMD:R_0805_2012Metric_Pad1.20x1.40mm_HandSolder | ~
33 | 4 | RC2, ROS1, ROS2, RPU1 | 12k | Device:R | Resistor_SMD:R_0805_2012Metric_Pad1.20x1.40mm_HandSolder | ~
34 | 1 | RD1 | 47 | Device:R | Resistor_SMD:R_0805_2012Metric_Pad1.20x1.40mm_HandSolder | ~
35 | 7 | RE2, RI2, RL2, RL3, RMX1, RP1, RPG1 | 2.2k | Device:R | Resistor_SMD:R_0805_2012Metric_Pad1.20x1.40mm_HandSolder | ~
36 | 5 | RE3, RL16, RL17, RL18, RL20 | 5.6k | Device:R | Resistor_SMD:R_0805_2012Metric_Pad1.20x1.40mm_HandSolder | ~
37 | 1 | RFB1 | 900k | Device:R | Resistor_SMD:R_0805_2012Metric_Pad1.20x1.40mm_HandSolder | ~
38 | 1 | RFB2 | 100k | Device:R | Resistor_SMD:R_0805_2012Metric_Pad1.20x1.40mm_HandSolder | ~
39 | 3 | RFD1, RL4, RL5 | 2.7k | Device:R | Resistor_SMD:R_0805_2012Metric_Pad1.20x1.40mm_HandSolder | ~
40 | 2 | RI1, RL1 | 39k | Device:R | Resistor_SMD:R_0805_2012Metric_Pad1.20x1.40mm_HandSolder | ~
41 | 4 | RL6, RL7, RL8, RL9 | 3.3k | Device:R | Resistor_SMD:R_0805_2012Metric_Pad1.20x1.40mm_HandSolder | ~
42 | 3 | RL10, RL11, RL12 | 3.9k | Device:R | Resistor_SMD:R_0805_2012Metric_Pad1.20x1.40mm_HandSolder | ~
43 | 3 | RL13, RL14, RL15 | 4.7k | Device:R | Resistor_SMD:R_0805_2012Metric_Pad1.20x1.40mm_HandSolder | ~
44 | 1 | RL21 | 8.2k | Device:R | Resistor_SMD:R_0805_2012Metric_Pad1.20x1.40mm_HandSolder | ~
45 | 1 | RP2 | 1.8k | Device:R | Resistor_SMD:R_0805_2012Metric_Pad1.20x1.40mm_HandSolder | ~
46 | 1 | RV1 | R_Potentiometer_Trim(100) | Device:R_Potentiometer_Trim | Potentiometer_SMD:Potentiometer_Bourns_3314J_Vertical | ~
47 | 2 | SW1, SW2 | SW_SPDT | Switch:SW_SPDT | OS102011MA1QN1:OS102011MA1QN1 | ~
48 | 1 | SW3 | SW_SP3T | Switch:SW_SP3T | OS103011MA7QP1:OS103011MA7QP1 | ~
49 | 11 | TPCAP1, TPMX1, TPOS1, TPOS2, TPVBAT1, TPVBUS1, TPVCC1, TPVO1, TPVO2, TPVO3, TPVO4 | TestPoint | Connector:TestPoint | TestPoint:TestPoint_Pad_D1.5mm | ~
50 | 1 | U1 | MCP73831T-4ADI_OT | MCP73831T-4ADI_OT:MCP73831T-4ADI_OT | Package_TO_SOT_SMD:TSOT-23-5_HandSoldering |  | https://componentsearchengine.com/Datasheets/1/MCP73831T-4ADI_OT.pdf | SOT95P270X145-5N | 1.45 | Microchip | MCP73831T-4ADI/OT | 579-MCP73831T4ADIOT | https://www.mouser.co.uk/ProductDetail/Microchip-Technology/MCP73831T-4ADI-OT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
51 | 1 | U2 | DIO6305B | LIB_DIO6305B_sym:DIO6305B | Package_TO_SOT_SMD:TSOT-23-6_HandSoldering
52 | 1 | VR1 | PTV09A-4025F-B102 | PTV09A-4025F-B102:PTV09A-4025F-B102 | PTV09A-4025F-B102:PTV09A4025FB102 | https://www.mouser.com/datasheet/2/54/ptv09-777818.pdf | https://datasheet.datasheetarchive.com/originals/dk/DKDS-12/224967.pdf | PTV09A4025FB102 | 25.5 | Bourns | PTV09A-4025F-B102 | 652-PTV09A-4025FB102 | https://www.mouser.co.uk/ProductDetail/Bourns/PTV09A-4025F-B102?qs=Qzws7J6gxqxMpvIOw8B%2F7Q%3D%3D
53 | 1 | VR2 | PTV09A-4025F-A103 | PTV09A-4025F-A103:PTV09A-4025F-A103 | PTV09A-4025F-A103:PTV09A4025FA103 | https://www.mouser.com/datasheet/2/54/ptv09-777818.pdf | https://www.bourns.com/docs/Product-Datasheets/PTV09.pdf | PTV09A4025FA103 | 25.5 | Bourns | PTV09A-4025F-A103 | 652-PTV09A4025FA103 | https://www.mouser.co.uk/ProductDetail/Bourns/PTV09A-4025F-A103?qs=%2FxQVPCMPNzjerVjIRRaAEA%3D%3D

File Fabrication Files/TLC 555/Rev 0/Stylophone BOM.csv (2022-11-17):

Id | Designation | Designator | Package | Quantity | Manufacturer | Manufacturer Part | Supplier Link
1 | USB_C_Receptacle_USB2.0 | J3 | GCTUSB4125GFA190 | 1 | Global Connector Technology (GCT) | USB4125-GF-A-0190 | https://www.mouser.com/ProductDetail/640-USB4125-GF-A-190
2 | TLC555xD | U1 | SOIC-8_3.9x4.9mm_P1.27mm | 1 | Texas Instruments | TLC555CD | https://www.mouser.com/ProductDetail/595-TLC555CD
3 | D_Schottky | D3,D1,D2 | D_SOD-123 | 3 | STMicroelectronics | STPS0530Z | https://www.mouser.com/ProductDetail/511-STPS0530Z
4 | 3.9k | R22,R30,R29,R31 | R_0402_1005Metric | 4 | YAGEO | RT0402FRE073K9L | https://www.mouser.com/ProductDetail/603-RT0402FRE073K9L
5 | PDB12-H4301-103BF | VR1 | PDB12H4301103BF | 1 | Bourns | PDB12-H4301-103BF | https://www.mouser.com/ProductDetail/652-PDB12-H4301103BF
6 | 5.6k | R23,R13,R12,R10 | R_0402_1005Metric | 4 | YAGEO | RT0402FRE075K6L | https://www.mouser.com/ProductDetail/603-RT0402FRE075K6L
7 | 39k | R21 | R_0402_1005Metric | 1 | YAGEO | RT0402FRE0739KL | https://www.mouser.com/ProductDetail/603-RT0402FRE0739KL
8 | 6.8k | R9,R8,R11,R7 | R_0402_1005Metric | 4 | YAGEO | RT0402FRE076K8L | https://www.mouser.com/ProductDetail/603-RT0402FRE076K8L
9 | MMBT3904L | Q2 | SOT-23 | 1 | onsemi | SMMBT3904LT1G | https://www.mouser.com/ProductDetail/863-SMMBT3904LT1G
10 | 4.7k | R15,R14 | R_0402_1005Metric | 2 | YAGEO | RT0402FRE074K7L | https://www.mouser.com/ProductDetail/603-RT0402FRE074K7L
11 | 2.7k | R25 | R_0402_1005Metric | 1 | YAGEO | RT0402DRE072K71L | https://www.mouser.com/ProductDetail/603-RT0402DRE072K71L
12 | 100k | R20 | R_0402_1005Metric | 1 | YAGEO | RT0402FRE07100KL | https://www.mouser.com/ProductDetail/603-RT0402FRE07100KL
13 | 3.3k | R24,R3,R26,R28,R27 | R_0402_1005Metric | 5 | YAGEO | RT0402FRE073K3L | https://www.mouser.com/ProductDetail/603-RT0402FRE073K3L
14 | 33k | R17,R18,R19 | R_0402_1005Metric | 3 | YAGEO | RT0402FRE0733KL | https://www.mouser.com/ProductDetail/603-RT0402FRE0733KL
15 | 5.1k | R1,R2 | R_0201_0603Metric | 2 | Vishay | TNPW02015K10BEED | https://www.mouser.com/ProductDetail/71-TNPW02015K10BEED
16 | 10n | C3 | C_0201_0603Metric | 1 | Samsung Electro-Mechanics | CL03A103KP3NNNC | https://www.mouser.com/ProductDetail/187-CL03A103KP3NNNC
17 | 0.47u | C6,C8,C7 | C_0603_1608Metric | 3 | Samsung Electro-Mechanics | CL10A474KO8NNNC | https://www.mouser.com/ProductDetail/187-CL10A474KO8NNNC
18 | 47n | C4 | C_0402_1005Metric | 1 | Samsung Electro-Mechanics | CL10B473KB8NNND | https://www.mouser.com/ProductDetail/187-CL10B473KB8NNND
19 | 100n | C1 | C_0402_1005Metric | 1 | Samsung Electro-Mechanics | CL05A104KP5NNNC | https://www.mouser.com/ProductDetail/187-CL05A104KP5NNNC
20 | CMS-160925-078SP-67 | LS1 | CMS160925078SP67 | 1 | CUI Devices | CMS-160925-078SP-67 | https://www.mouser.com/ProductDetail/490-CMS160925078SP67
21 | 1u | C5,C2 | C_0603_1608Metric | 2 | Samsung Electro-Mechanics | CL10A105KP8NNNL | https://www.mouser.com/ProductDetail/187-CL10A105KP8NNNL
22 | 220k | R16 | R_0402_1005Metric | 1 | YAGEO | RT0402FRE07220KL | https://www.mouser.com/ProductDetail/603-RT0402FRE07220KL
23 | 220u | C9 | CP_Elec_6.3x7.7 | 1 | Lelon | VZL221M1CTR-0607 | https://www.mouser.com/ProductDetail/140-VZL221M1CTR-0607
24 | PDB12-H4301-105BF | VR2 | PDB12H4301105BF | 1 | Bourns | PDB12-H4301-105BF | https://www.mouser.com/ProductDetail/652-PDB12-H4301105BF
25 | 68k | R4 | R_0402_1005Metric | 1 | YAGEO | RT0402FRE0768KL | https://www.mouser.com/ProductDetail/603-RT0402FRE0768KL
26 | 8.2k | R6 | R_0402_1005Metric | 1 | YAGEO | RT0402FRE078K2L | https://www.mouser.com/ProductDetail/603-RT0402FRE078K2L
27 | 2N7002L | Q1 | SOT-23 | 1 | onsemi | 2N7002LT1G | https://www.mouser.com/ProductDetail/863-2N7002LT1G
28 | 1k | R32 | R_0402_1005Metric | 1 | YAGEO | RT0402FRE071KL | https://www.mouser.com/ProductDetail/603-RT0402FRE071KL
29 | 1.3k | R5 | R_0402_1005Metric | 1 | YAGEO | RT0402FRE071K3L | https://www.mouser.com/ProductDetail/603-RT0402FRE071K3L
30 | R_Potentiometer_Trim(50) | RV1 | Potentiometer_Bourns_3314J_Vertical | 1 | Bourns | 3314J-1-500E | https://www.mouser.com/ProductDetail/652-3314J-1-500E
31 | SW1 | SW_SPDT | OS102011MA1QN1 | 1 | C&K Switches | OS102011MA1QN1 | https://www.mouser.com/ProductDetail/611-OS102011MA1QN1

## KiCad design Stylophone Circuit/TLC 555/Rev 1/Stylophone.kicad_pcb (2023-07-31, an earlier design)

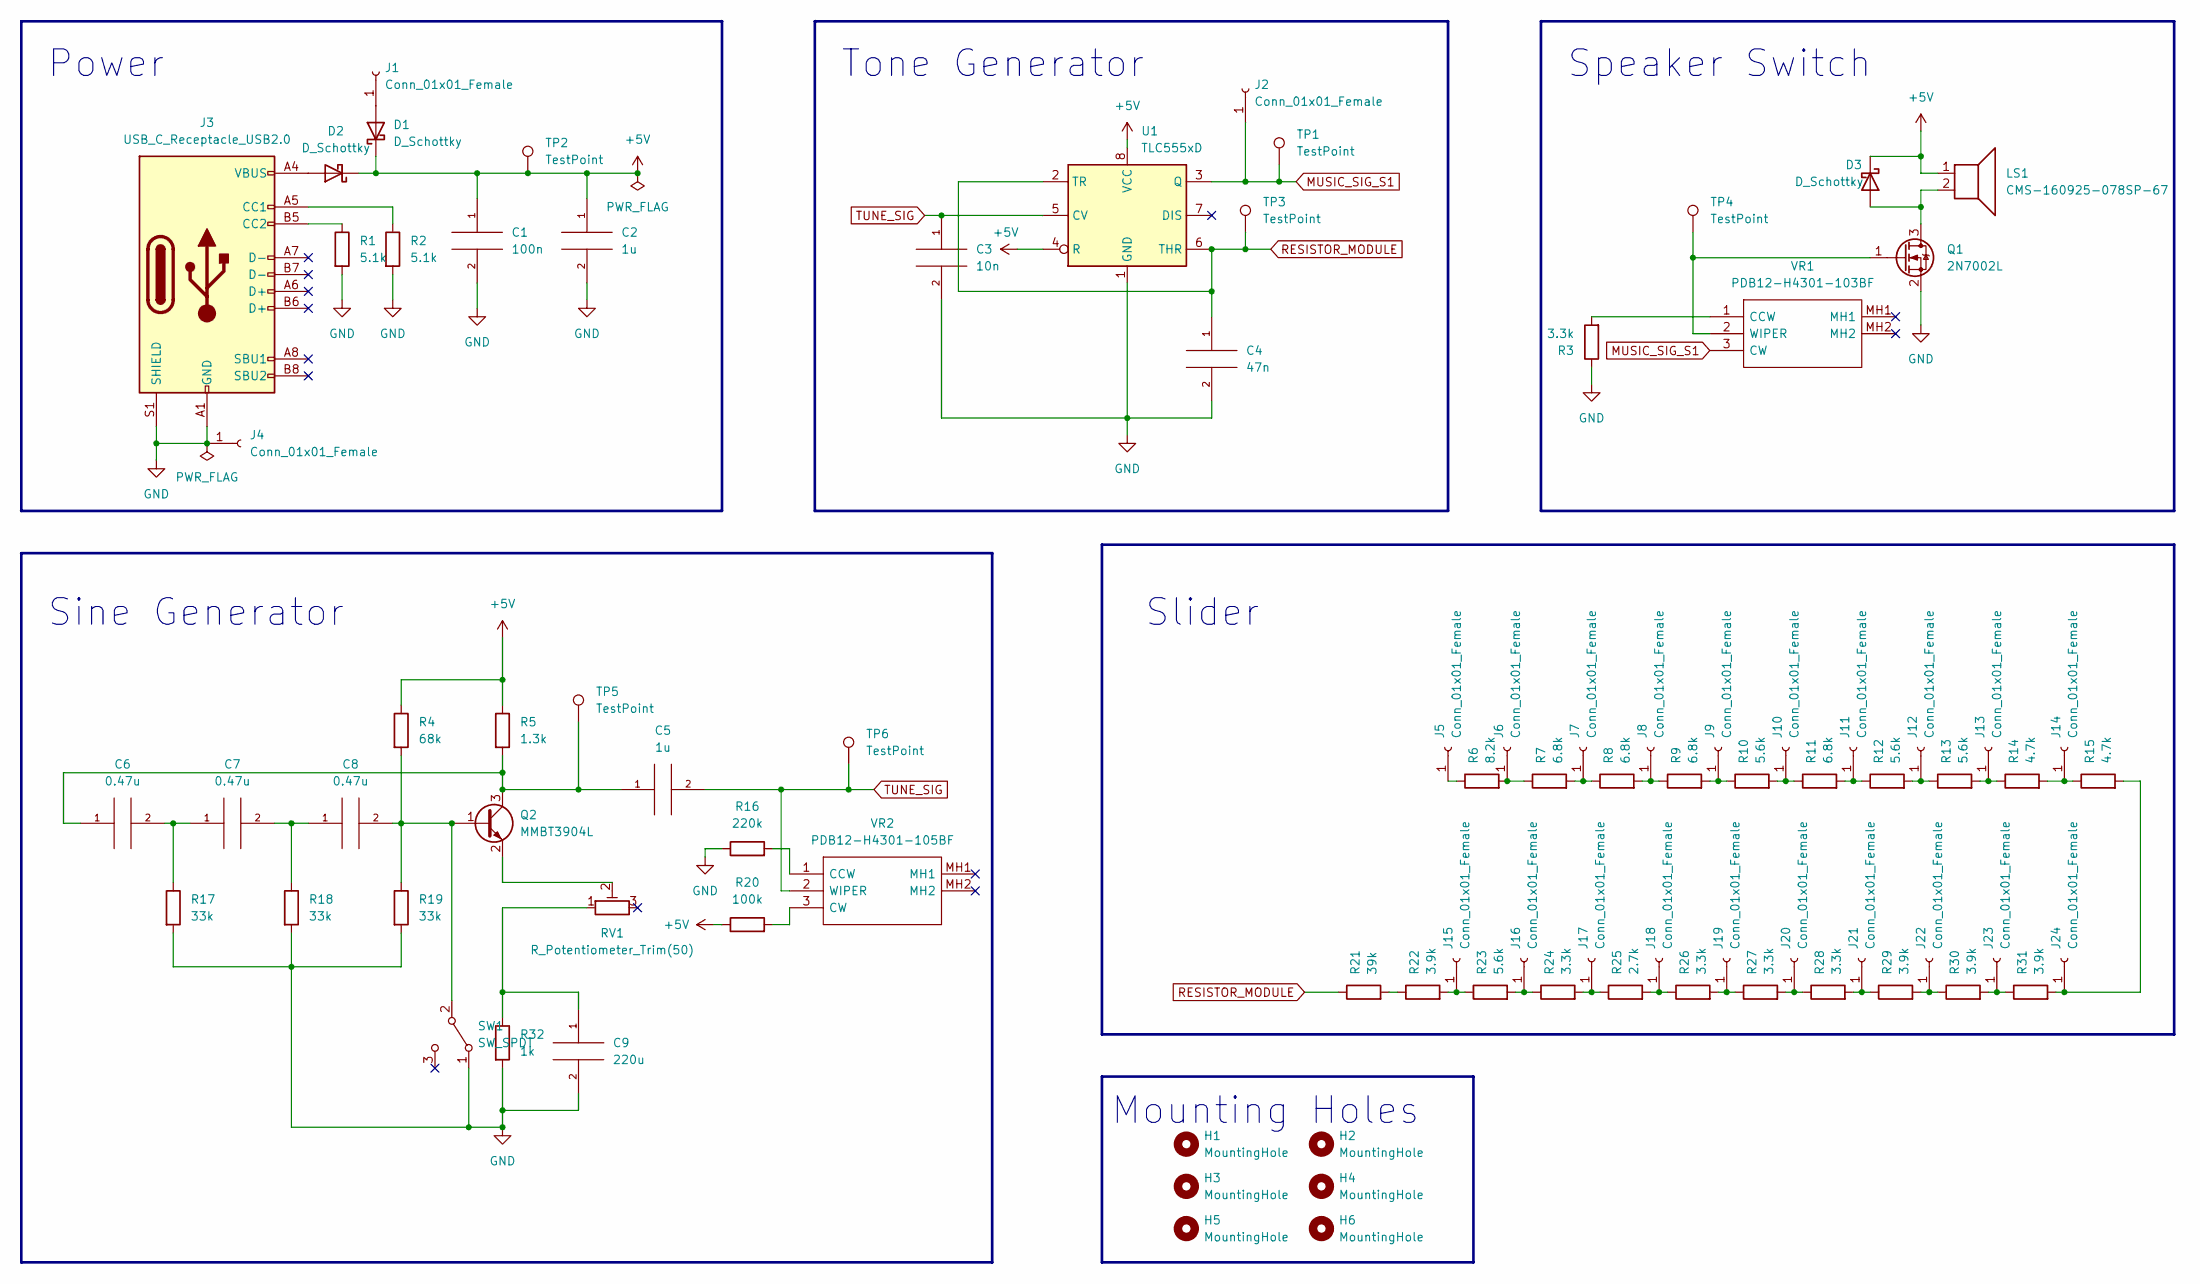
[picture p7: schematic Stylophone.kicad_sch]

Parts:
C1: 100n; C_0402_1005Metric
C2, C5: 1u; C_0603_1608Metric
C3: 10n; C_0201_0603Metric
C4: 47n; C_0402_1005Metric
C6, C7, C8: 0.47u; C_0603_1608Metric
C9: 220u; CP_Elec_6.3x7.7
D1, D2, D3: D_Schottky; D_SOD-123
H1, H2, H3, H4, H5, H6: MountingHole; MountingHole_2.7mm_M2.5
J1, J2, J4: Conn_01x01_Female; SolderWirePad_1x01_SMD_1x2mm
J3: USB_C_Receptacle_USB2.0; GCTUSB4125GFA190
J5, J8, J13, J19: Conn_01x01_Female; Note-Left
J6, J9, J11, J14, J16, J18, J21, J23: Conn_01x01_Female; Note-Sharp
J7, J12, J15, J20: Conn_01x01_Female; Note-Right
J10, J17, J22, J24: Conn_01x01_Female; Note-Center
LS1: CMS-160925-078SP-67; CMS160925078SP67
Q1: 2N7002L; SOT-23
Q2: MMBT3904L; SOT-23
R1, R2: 5.1k; R_0201_0603Metric
R3, R24, R26, R27, R28: 3.3k; R_0402_1005Metric
R4: 68k; R_0402_1005Metric
R5: 1.3k; R_0402_1005Metric
R6: 8.2k; R_0402_1005Metric
R7, R8, R9, R11: 6.8k; R_0402_1005Metric
R10, R12, R13, R23: 5.6k; R_0402_1005Metric
R14, R15: 4.7k; R_0402_1005Metric
R16: 220k; R_0402_1005Metric
R17, R18, R19: 33k; R_0402_1005Metric
R20: 100k; R_0402_1005Metric
R21: 39k; R_0402_1005Metric
R22, R29, R30, R31: 3.9k; R_0402_1005Metric
R25: 2.7k; R_0402_1005Metric
R32: 1k; R_0402_1005Metric
RV1: R_Potentiometer_Trim(50); Potentiometer_Bourns_3314J_Vertical
SW1: SW_SPDT; OS102011MA1QN1
TP1, TP2, TP3, TP4, TP5, TP6: TestPoint; TestPoint_Pad_D1.5mm
U1: TLC555xD; SOIC-8_3.9x4.9mm_P1.27mm
VR1: PDB12-H4301-103BF; PDB12H4301103BF; Mouser Part Number 652-PDB12-H4301103BF
VR2: PDB12-H4301-105BF; PDB12H4301105BF; Mouser Part Number 652-PDB12-H4301105BF

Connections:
+5V: C1.1, C2.1, D1.1 (K), D2.1 (K), D3.1 (K), LS1.1, R4.1, R5.1, R20.1, TP2.1, U1.4 (R), U1.8 (VCC)
GND: C1.2, C2.2, C3.2, C4.2, C9.2, J3.A1 (GND), J3.A12 (GND), J3.B1 (GND), J3.B12 (GND), J3.S1 (SHIELD), J4.1, Q1.2 (S), R1.2, R2.2, R3.1, R16.1, R17.2, R18.2, R19.2, R32.2, SW1.1 (A), U1.1 (GND)
MUSIC_SIG_S1: J2.1, TP1.1, U1.3 (Q), VR1.3 (CW)
unnamed: C5.1, C6.1, Q2.3 (C), R5.2, TP5.1
unnamed: C6.2, C7.1, R17.1
unnamed: C7.2, C8.1, R18.1
unnamed: C8.2, Q2.1 (B), R4.2, R19.1, SW1.2 (B)
unnamed: C9.1, R32.1, RV1.1
unnamed: D1.2 (A), J1.1
unnamed: D2.2 (A), J3.A4 (VBUS), J3.A9 (VBUS), J3.B4 (VBUS), J3.B9 (VBUS)
unnamed: D3.2 (A), LS1.2, Q1.3 (D)
unnamed: J3.A5 (CC1), R2.1
unnamed: J3.B5 (CC2), R1.1
unnamed: J5.1, R6.1
unnamed: J6.1, R6.2, R7.1
unnamed: J7.1, R7.2, R8.1
unnamed: J8.1, R8.2, R9.1
unnamed: J9.1, R9.2, R10.1
unnamed: J10.1, R10.2, R11.1
unnamed: J11.1, R11.2, R12.1
unnamed: J12.1, R12.2, R13.1
unnamed: J13.1, R13.2, R14.1
unnamed: J14.1, R14.2, R15.1
unnamed: J15.1, R22.2, R23.1
unnamed: J16.1, R23.2, R24.1
unnamed: J17.1, R24.2, R25.1
unnamed: J18.1, R25.2, R26.1
unnamed: J19.1, R26.2, R27.1
unnamed: J20.1, R27.2, R28.1
unnamed: J21.1, R28.2, R29.1
unnamed: J22.1, R29.2, R30.1
unnamed: J23.1, R30.2, R31.1
unnamed: J24.1, R15.2, R31.2
unnamed: Q1.1 (G), TP4.1, VR1.2 (WIPER)
unnamed: Q2.2 (E), RV1.2
unnamed: R3.2, VR1.1 (CCW)
unnamed: R16.2, VR2.1 (CCW)
unnamed: R20.2, VR2.3 (CW)
unnamed: R21.2, R22.1
RESISTOR_MODULE: C4.1, R21.1, TP3.1, U1.2 (TR), U1.6 (THR)
TUNE_SIG: C3.1, C5.2, TP6.1, U1.5 (CV), VR2.2 (WIPER)

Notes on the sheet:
Tone Generator
Mounting Holes
Power
Speaker Switch
Sine Generator
Slider

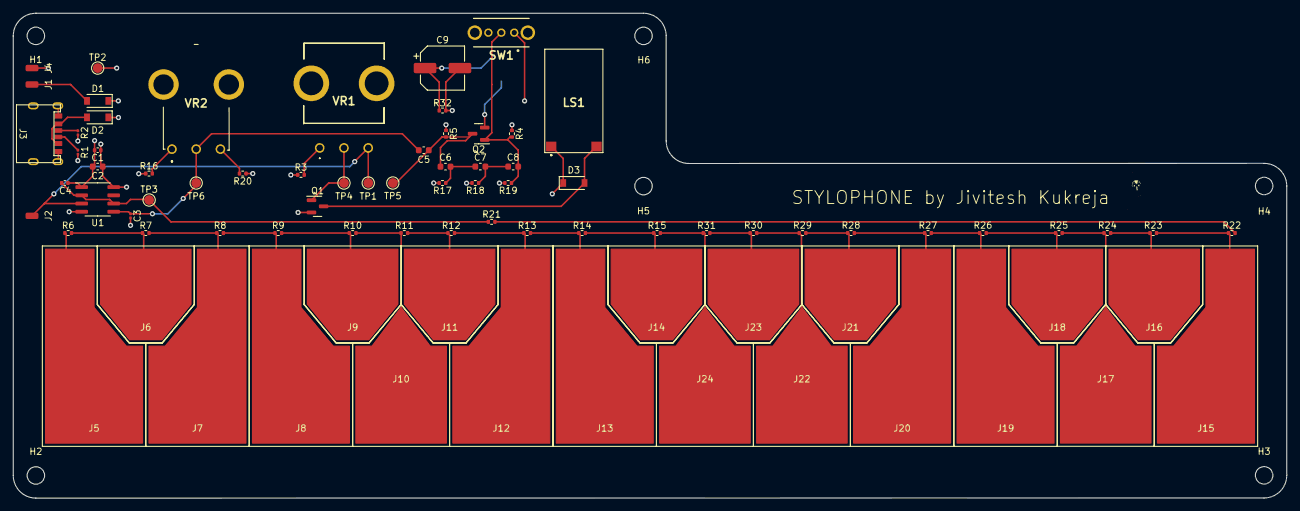
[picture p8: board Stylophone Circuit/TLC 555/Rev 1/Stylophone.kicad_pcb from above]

Board: 4 copper layers, 197.0 x 75.0 mm, 88 parts (1 on the bottom side), 41 nets.

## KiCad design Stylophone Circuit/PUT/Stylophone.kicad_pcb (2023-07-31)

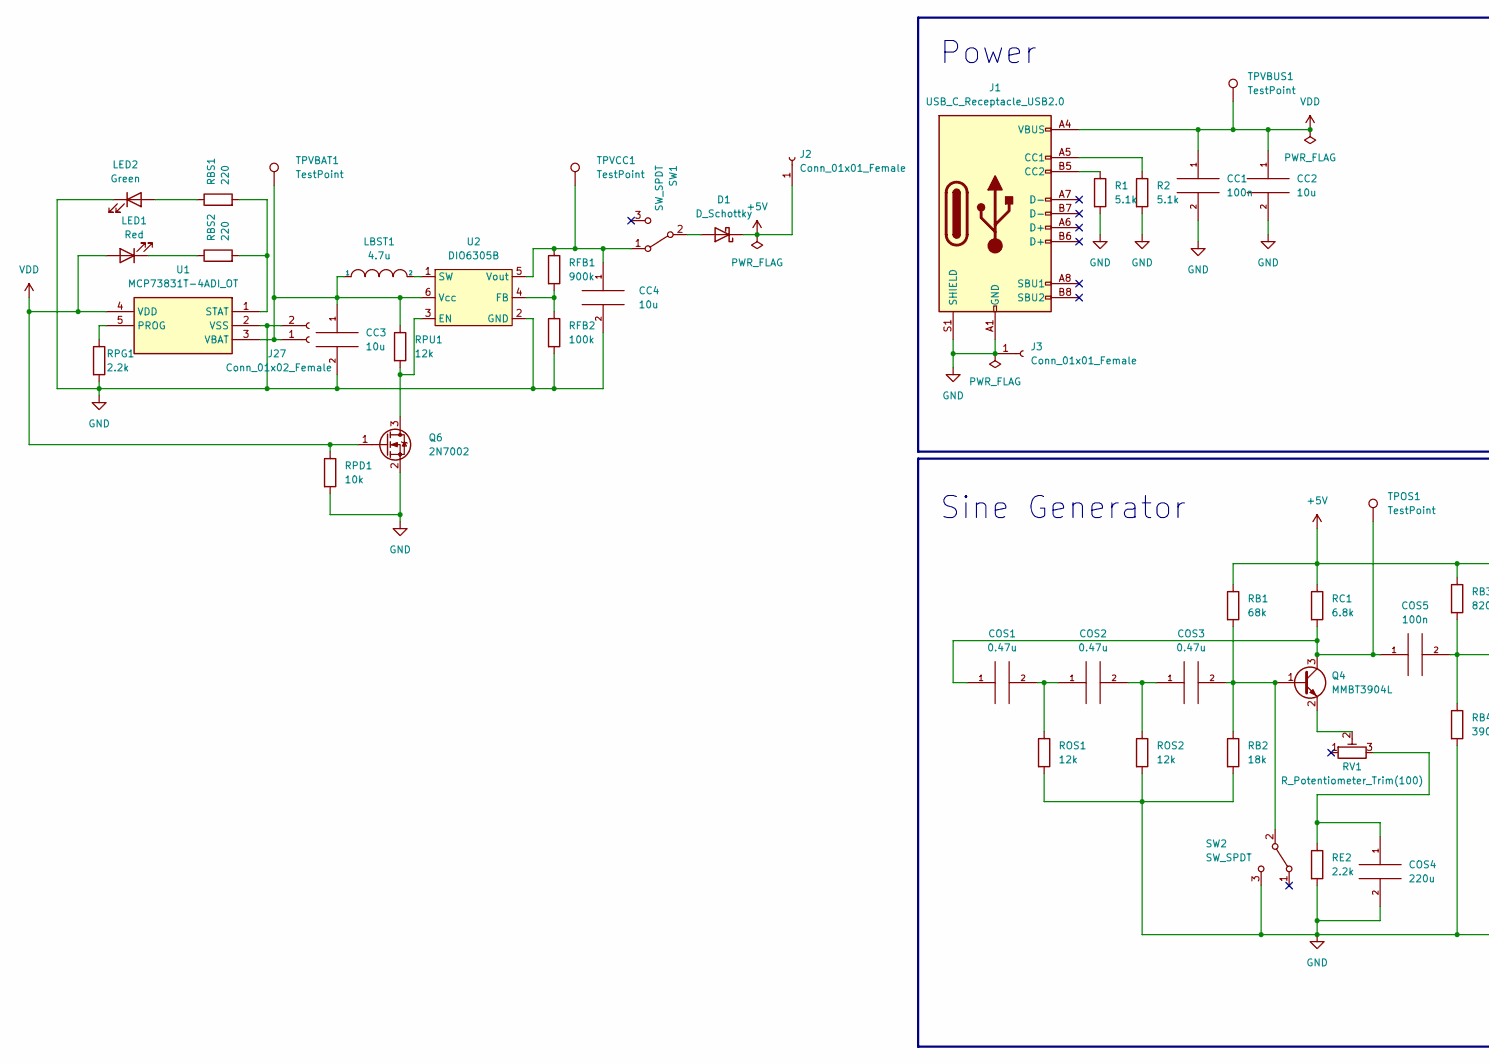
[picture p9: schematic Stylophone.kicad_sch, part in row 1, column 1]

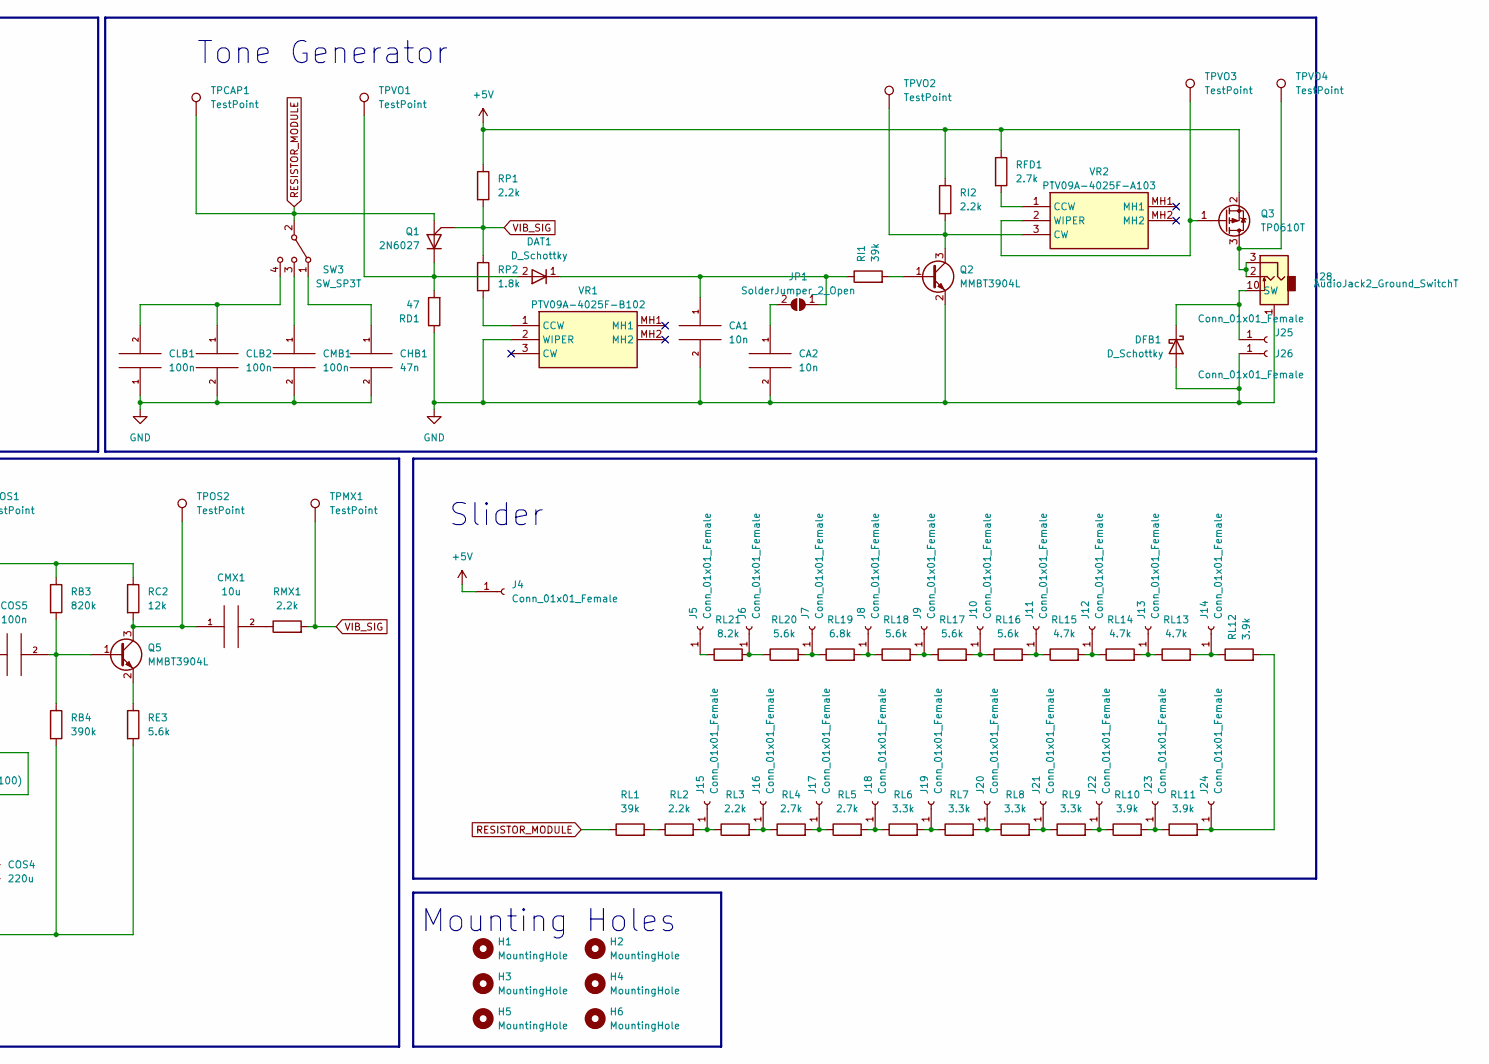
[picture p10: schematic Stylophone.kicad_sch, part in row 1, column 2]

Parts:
CA1, CA2: 10n; C_0603_1608Metric_Pad1.08x0.95mm_HandSolder
CC1: 100n; C_0603_1608Metric_Pad1.08x0.95mm_HandSolder
CC2, CC3, CC4: 10u; C_1206_3216Metric_Pad1.33x1.80mm_HandSolder
CHB1: 47n; C_0603_1608Metric_Pad1.08x0.95mm_HandSolder
CLB1, CLB2: 100n; C_0603_1608Metric_Pad1.08x0.95mm_HandSolder
CMB1: 100n; C_0603_1608Metric_Pad1.08x0.95mm_HandSolder
CMX1: 10u; C_1206_3216Metric_Pad1.33x1.80mm_HandSolder
COS1, COS2, COS3: 0.47u; C_0805_2012Metric_Pad1.18x1.45mm_HandSolder
COS4: 220u; CP_Elec_6.3x7.7
COS5: 100n; C_0603_1608Metric_Pad1.08x0.95mm_HandSolder
D1: D_Schottky; D_SOD-123
DAT1: D_Schottky; D_SOD-123; Mouser Part Number 512-S1A
DFB1: D_Schottky; D_SOD-123
H1, H2, H3, H4, H5, H6: MountingHole; MountingHole_2.7mm_M2.5
J1: USB_C_Receptacle_USB2.0; GCTUSB4125GFA190
J2, J3, J4, J25, J26: Conn_01x01_Female; SolderWirePad_1x01_SMD_1x2mm
J5, J8, J13, J19: Conn_01x01_Female; Note-Left
J6, J9, J11, J14, J16, J18, J21, J23: Conn_01x01_Female; Note-Sharp
J7, J12, J15, J20: Conn_01x01_Female; Note-Right
J10, J17, J22, J24: Conn_01x01_Female; Note-Center
J27: Conn_01x02_Female; JST_PH_S2B-PH-K_1x02_P2.00mm_Horizontal
J28: AudioJack2_Ground_SwitchT; SJ23593BSMTTR
JP1: SolderJumper_2_Open; SolderJumper-2_P1.3mm_Open_TrianglePad1.0x1.5mm
LBST1: 4.7u; 74408053004_5030
LED1: Red; LED_0603_1608Metric_Pad1.05x0.95mm_HandSolder
LED2: Green; LED_0603_1608Metric_Pad1.05x0.95mm_HandSolder
Q1: 2N6027; TO-92_Inline_Horizontal2
Q2, Q4, Q5: MMBT3904L; SOT-23
Q3: TP0610T; SOT-23
Q6: 2N7002; SOT-23
R1, R2: 5.1k; R_0805_2012Metric_Pad1.20x1.40mm_HandSolder
RB1: 68k; R_0805_2012Metric_Pad1.20x1.40mm_HandSolder
RB2: 18k; R_0805_2012Metric_Pad1.20x1.40mm_HandSolder
RB3: 820k; R_0805_2012Metric_Pad1.20x1.40mm_HandSolder
RB4: 390k; R_0805_2012Metric_Pad1.20x1.40mm_HandSolder
RBS1, RBS2: 220; R_0805_2012Metric_Pad1.20x1.40mm_HandSolder
RC1: 6.8k; R_0805_2012Metric_Pad1.20x1.40mm_HandSolder
RC2: 12k; R_0805_2012Metric_Pad1.20x1.40mm_HandSolder
RD1: 47; R_0805_2012Metric_Pad1.20x1.40mm_HandSolder
RE2: 2.2k; R_0805_2012Metric_Pad1.20x1.40mm_HandSolder
RE3: 5.6k; R_0805_2012Metric_Pad1.20x1.40mm_HandSolder
RFB1: 900k; R_0805_2012Metric_Pad1.20x1.40mm_HandSolder
RFB2: 100k; R_0805_2012Metric_Pad1.20x1.40mm_HandSolder
RFD1: 2.7k; R_0805_2012Metric_Pad1.20x1.40mm_HandSolder
RI1: 39k; R_0805_2012Metric_Pad1.20x1.40mm_HandSolder
RI2: 2.2k; R_0805_2012Metric_Pad1.20x1.40mm_HandSolder
RL1: 39k; R_0805_2012Metric_Pad1.20x1.40mm_HandSolder
RL2, RL3: 2.2k; R_0805_2012Metric_Pad1.20x1.40mm_HandSolder
RL4, RL5: 2.7k; R_0805_2012Metric_Pad1.20x1.40mm_HandSolder
RL6, RL7, RL8, RL9: 3.3k; R_0805_2012Metric_Pad1.20x1.40mm_HandSolder
RL10, RL11, RL12: 3.9k; R_0805_2012Metric_Pad1.20x1.40mm_HandSolder
RL13, RL14, RL15: 4.7k; R_0805_2012Metric_Pad1.20x1.40mm_HandSolder
RL16, RL17, RL18, RL20: 5.6k; R_0805_2012Metric_Pad1.20x1.40mm_HandSolder
RL19: 6.8k; R_0805_2012Metric_Pad1.20x1.40mm_HandSolder
RL21: 8.2k; R_0805_2012Metric_Pad1.20x1.40mm_HandSolder
RMX1: 2.2k; R_0805_2012Metric_Pad1.20x1.40mm_HandSolder
ROS1, ROS2: 12k; R_0805_2012Metric_Pad1.20x1.40mm_HandSolder
RP1: 2.2k; R_0805_2012Metric_Pad1.20x1.40mm_HandSolder
RP2: 1.8k; R_0805_2012Metric_Pad1.20x1.40mm_HandSolder
RPD1: 10k; R_0805_2012Metric_Pad1.20x1.40mm_HandSolder
RPG1: 2.2k; R_0805_2012Metric_Pad1.20x1.40mm_HandSolder
RPU1: 12k; R_0805_2012Metric_Pad1.20x1.40mm_HandSolder
RV1: R_Potentiometer_Trim(100); TC33X2503E
SW1, SW2: SW_SPDT; OS102011MA1QN1
SW3: SW_SP3T; OS103011MA7QP1
TPCAP1: TestPoint; TestPoint_Pad_D1.5mm
TPMX1: TestPoint; TestPoint_Pad_D1.5mm
TPOS1, TPOS2: TestPoint; TestPoint_Pad_D1.5mm
TPVBAT1: TestPoint; TestPoint_Pad_D1.5mm
TPVBUS1: TestPoint; TestPoint_Pad_D1.5mm
TPVCC1: TestPoint; TestPoint_Pad_D1.5mm
TPVO1, TPVO2, TPVO3, TPVO4: TestPoint; TestPoint_Pad_D1.5mm
U1: MCP73831T-4ADI_OT; TSOT-23-5_HandSoldering; Mouser Part Number 579-MCP73831T4ADIOT
U2: DIO6305B; TSOT-23-6_HandSoldering
VR1: PTV09A-4025F-B102; PTV09A4025FB102; Mouser Part Number 652-PTV09A-4025FB102
VR2: PTV09A-4025F-A103; PTV09A4025FA103; Mouser Part Number 652-PTV09A4025FA103

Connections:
+5V: D1.1 (K), J2.1, J4.1, Q3.2 (S), RB1.1, RB3.1, RC1.1, RC2.1, RFD1.1, RI2.1, RP1.1
GND: CA1.2, CA2.2, CC1.2, CC2.2, CC3.2, CC4.2, CHB1.2, CLB1.1, CLB2.2, CMB1.2, COS4.2, DFB1.2 (A), J1.A1 (GND), J1.A12 (GND), J1.B1 (GND), J1.B12 (GND), J1.S1 (SHIELD), J3.1, J26.1, J27.2, J28.1, LED2.1 (K), Q2.2 (E), Q6.2 (S), R1.2, R2.2, RB2.2, RB4.2, RD1.1, RE2.2, RE3.2, RFB2.2, ROS1.2, ROS2.2, RPD1.2, RPG1.2, SW2.3 (C), U1.2 (VSS), U2.2 (GND), VR1.2 (WIPER)
unnamed: CA1.1, DAT1.1 (K), JP1.1 (A), RI1.1
unnamed: CA2.1, JP1.2 (B)
unnamed: CC3.1, J27.1, LBST1.1, RPU1.1, TPVBAT1.1, U1.3 (VBAT), U2.6 (Vcc)
unnamed: CC4.1, RFB1.1, SW1.1 (A), TPVCC1.1, U2.5 (Vout)
unnamed: CHB1.1, SW3.1
unnamed: CLB1.2, CLB2.1, SW3.4
unnamed: CMB1.1, SW3.3
unnamed: CMX1.1, Q5.3 (C), RC2.2, TPOS2.1
unnamed: CMX1.2, RMX1.1
unnamed: COS1.1, COS5.1, Q4.3 (C), RC1.2, TPOS1.1
unnamed: COS1.2, COS2.1, ROS1.1
unnamed: COS2.2, COS3.1, ROS2.1
unnamed: COS3.2, Q4.1 (B), RB1.2, RB2.1, SW2.2 (B)
unnamed: COS4.1, RE2.1, RV1.3
unnamed: COS5.2, Q5.1 (B), RB3.2, RB4.1
unnamed: D1.2 (A), SW1.2 (B)
unnamed: DAT1.2 (A), Q1.3 (Cathode), RD1.2, TPVO1.1
unnamed: DFB1.1 (K), J25.1, J28.10 (SW)
unnamed: J1.A5 (CC1), R2.1
unnamed: J1.B5 (CC2), R1.1
unnamed: J5.1, RL21.1
unnamed: J6.1, RL20.1, RL21.2
unnamed: J7.1, RL19.1, RL20.2
unnamed: J8.1, RL18.1, RL19.2
unnamed: J9.1, RL17.1, RL18.2
unnamed: J10.1, RL16.1, RL17.2
unnamed: J11.1, RL15.1, RL16.2
unnamed: J12.1, RL14.1, RL15.2
unnamed: J13.1, RL13.1, RL14.2
unnamed: J14.1, RL12.1, RL13.2
unnamed: J15.1, RL2.2, RL3.1
unnamed: J16.1, RL3.2, RL4.1
unnamed: J17.1, RL4.2, RL5.1
unnamed: J18.1, RL5.2, RL6.1
unnamed: J19.1, RL6.2, RL7.1
unnamed: J20.1, RL7.2, RL8.1
unnamed: J21.1, RL8.2, RL9.1
unnamed: J22.1, RL9.2, RL10.1
unnamed: J23.1, RL10.2, RL11.1
unnamed: J24.1, RL11.2, RL12.2
unnamed: J28.2, J28.3, Q3.3 (D), TPVO4.1
unnamed: LBST1.2, U2.1 (SW)
unnamed: LED1.1 (K), RBS2.1
unnamed: LED2.2 (A), RBS1.1
unnamed: Q2.1 (B), RI1.2
unnamed: Q2.3 (C), RI2.2, TPVO2.1, VR2.3 (CW)
unnamed: Q3.1 (G), TPVO3.1, VR2.2 (WIPER)
unnamed: Q4.2 (E), RV1.2
unnamed: Q5.2 (E), RE3.1
unnamed: Q6.3 (D), RPU1.2, U2.3 (EN)
unnamed: RBS1.2, RBS2.2, U1.1 (STAT)
unnamed: RFB1.2, RFB2.1, U2.4 (FB)
unnamed: RFD1.2, VR2.1 (CCW)
unnamed: RL1.2, RL2.1
unnamed: RP2.2, VR1.1 (CCW)
unnamed: RPG1.1, U1.5 (PROG)
RESISTOR_MODULE: Q1.1 (Anode), RL1.1, SW3.2, TPCAP1.1
VDD: CC1.1, CC2.1, J1.A4 (VBUS), J1.A9 (VBUS), J1.B4 (VBUS), J1.B9 (VBUS), LED1.2 (A), Q6.1 (G), RPD1.1, TPVBUS1.1, U1.4 (VDD)
VIB_SIG: Q1.2 (Gate), RMX1.2, RP1.2, RP2.1, TPMX1.1

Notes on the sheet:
Tone Generator
Mounting Holes
Power
Sine Generator
Slider

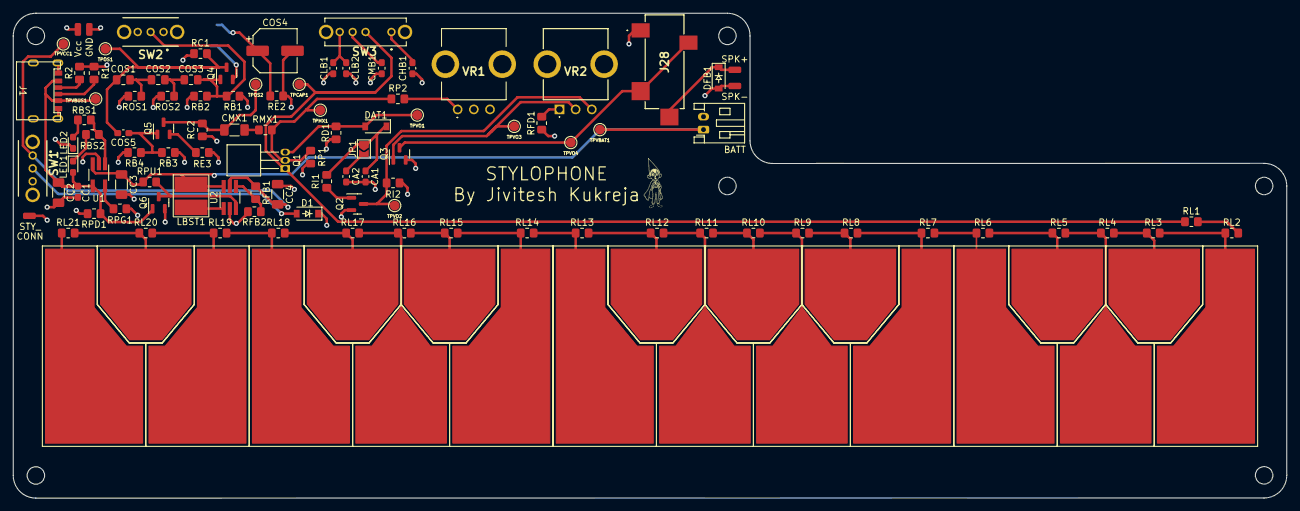
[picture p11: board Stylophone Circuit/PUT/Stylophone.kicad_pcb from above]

Board: 4 copper layers, 197.0 x 75.0 mm, 130 parts (1 on the bottom side), 61 nets.

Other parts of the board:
G1: LOGO

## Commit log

2022-11-09 Added fabrication files and bom
    [Stylophone BOM.csv]
2022-11-17 Updated BOM and page
    [Stylophone BOM.csv]
2023-07-31 added analog version
    [Stylophone BOM.csv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]
2023-07-31 fixed bom for analog version
    [Stylophone_with_battery.csv]
